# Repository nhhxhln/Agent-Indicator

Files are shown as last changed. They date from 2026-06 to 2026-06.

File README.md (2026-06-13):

# Agent Indicator

中文 | [English](README.en.md)

> 一个为 LLM Agent 打造的状态指示桌搭:让 Claude Code 的思考、回复、工具调用、
> 用量与 context 占用,变成桌面上一眼可读的光与屏。

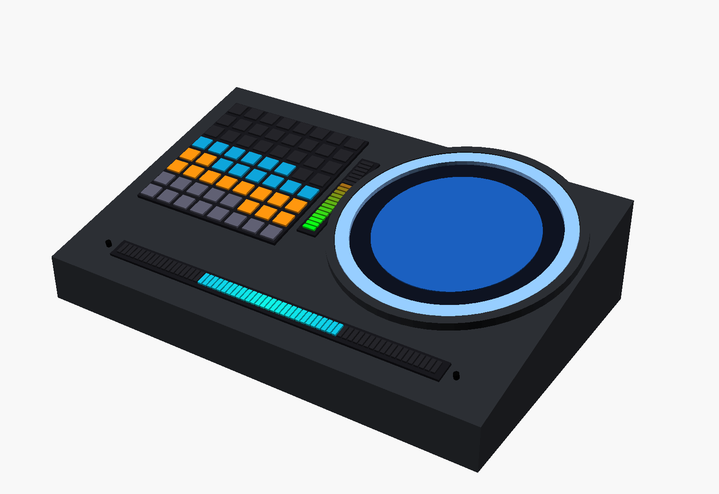
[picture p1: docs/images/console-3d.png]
Console 主力款


## ✨ 它能做什么

| 信息 | 载体 | 效果 |
|---|---|---|
| Agent 状态 | RGB Circle ×24 | 思考=紫色彗星旋转 · 回复=绿色流光 · 工具=双彗星对转 · 等待=蓝色呼吸 |
| Context 占用 | RGB Matrix 8×8(可 4 块拼 16×16) | 按 system/tools/mcp/memory/messages 分类的热力图 |
| 用量额度 | RGB Bar 20LED | 会话/5h 限额双段渐变条 |
| 输入输出 | 480×480 圆形视觉 LCD + 触摸 | 文本流 + 六页触摸 UI |
| 拾音电平 | RGB Bar(最长 160LED@329mm) | 中心展开 VU,MIC 本地闭环 |
| 提示音 | ES8311 + 3W PA | 完成/注意/错误三种音色 |
| 灯效模式 | 全部灯带 | OpenRGB 风格:常亮(调色)/呼吸/跑马灯/彩虹/关闭 |
| 环境传感 | SHT4x / BMP280 / PCF8563 | 温湿度 / 气压 / RTC 时钟,Devices 页实时显示 |
| 界面主题 | LCD | Light / Dark 双主题,Devices 页一键切换,NVS 持久化 |

**三链路接入**:Wi-Fi(WebSocket + mDNS 自发现)/ CAN(SocketCAN)/ USB 自定义端点,
同时在线自动择路。**电源**:USB-PD 15V / XT30 12-24V / 3×18650 平衡充,NVDC 无缝切换。

## 🖼️ 外观方案(6 款,共用同一主板)

| A「Halo」圆形单体 | D「Tiles」磁吸模块 | F「Orb」球形桌宠 |
|:---:|:---:|:---:|
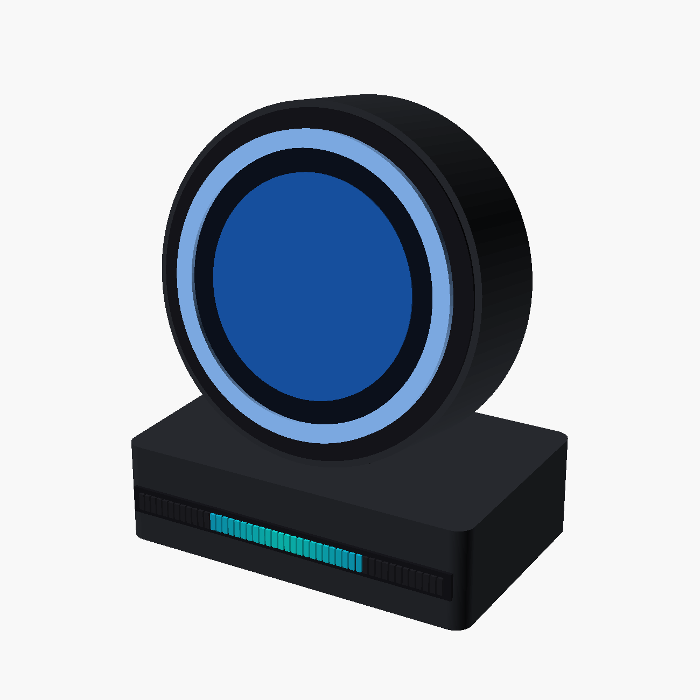
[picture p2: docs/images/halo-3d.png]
Halo
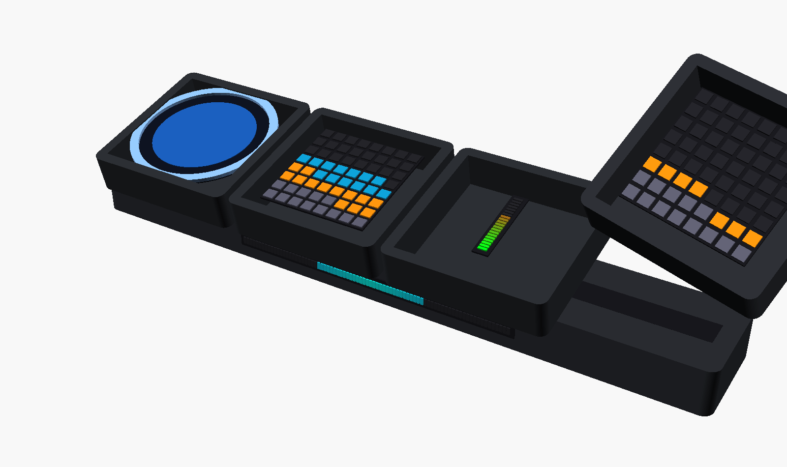
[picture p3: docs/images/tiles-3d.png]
Tiles
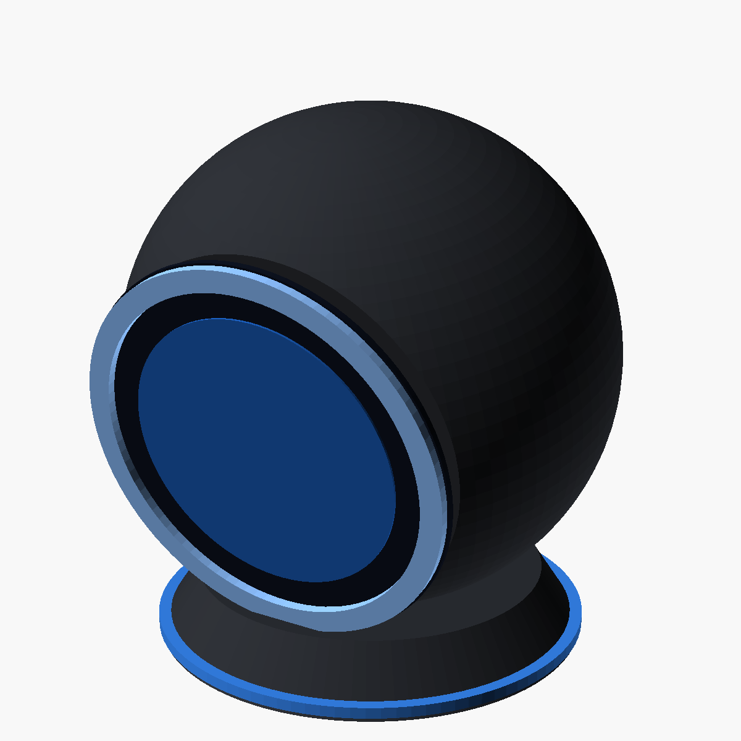
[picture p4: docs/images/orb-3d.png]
Orb
|  |  |  |

| B「Console」(推荐主力款) | E「Soundbar」(显示器下横条) |
|:---:|:---:|
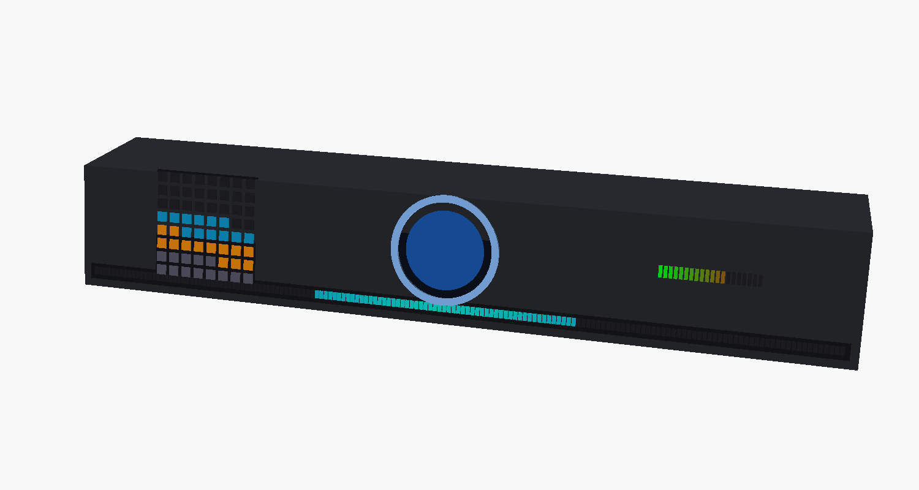
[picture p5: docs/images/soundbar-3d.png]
Soundbar
| Console |  |

> 另有 C「Totem」竖塔款,详见 [外观设计文档](docs/03-industrial-design.md)。

## 📱 屏幕 UI(六页 + Light/Dark 主题,PC 模拟器渲染 = 固件像素一致)

| Home 状态+IO 流 | Lighting 灯效 | Wi-Fi 连接 |
|:---:|:---:|:---:|
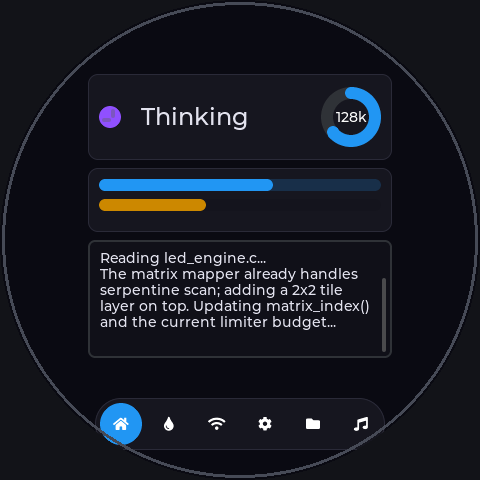
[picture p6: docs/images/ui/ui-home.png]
Home
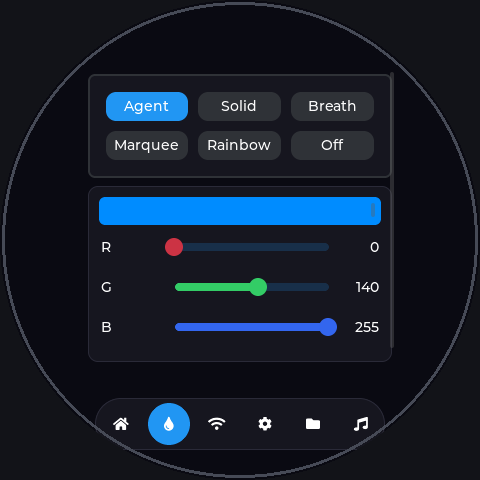
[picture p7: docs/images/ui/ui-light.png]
Lighting
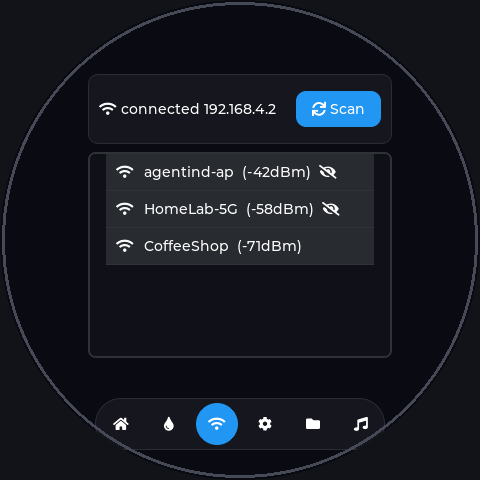
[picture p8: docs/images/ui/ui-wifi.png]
Wi-Fi
|  |  |  |

| Devices 检测+传感器 | Files 浏览 | Music 播放 |
|:---:|:---:|:---:|
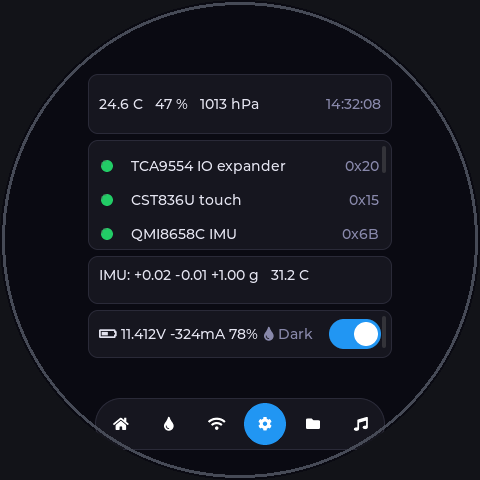
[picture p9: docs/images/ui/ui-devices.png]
Devices
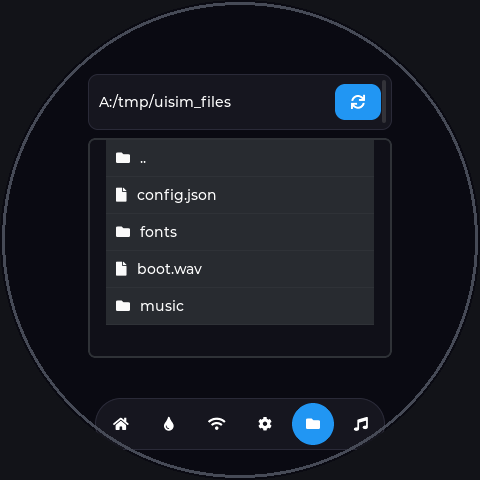
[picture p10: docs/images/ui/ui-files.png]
Files
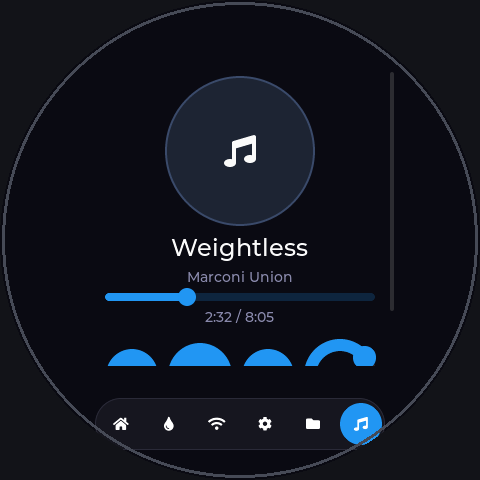
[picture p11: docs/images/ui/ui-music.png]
Music
|  |  |  |

| Dark 主题(默认) | Light 主题 |
|:---:|:---:|
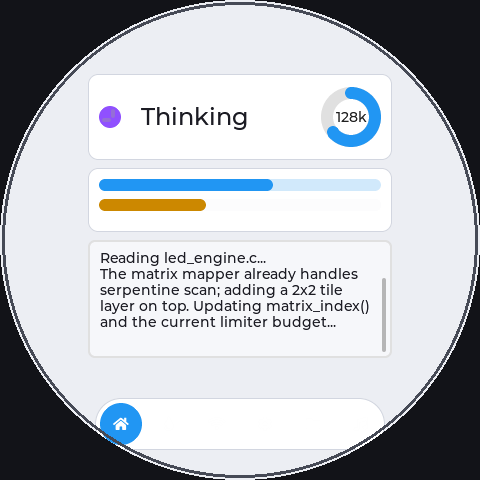
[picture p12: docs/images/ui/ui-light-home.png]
Home light
| Home dark |  |

## 🚀 快速开始

```bash
# 1. 固件(ESP-IDF v5.2)
cd firmware && idf.py set-target esp32s3 && idf.py menuconfig   # 填 Wi-Fi SSID
idf.py build flash monitor

# 2. 上位机(PC 先建好 AP)
cd host && pip install -e . && agentind run        # Claude Code 状态自动转发
agentind run -s demo -v                             # 或先跑演示动画联调

# 3. UI 模拟器(可选,PC 上改 UI 不烧板)
cd tools/ui_sim && cmake -B build && cmake --build build -j && ./build/ui_sim shots/
```

## 📚 文档导航

| 文档 | 内容 |
|---|---|
| [01 系统设计](docs/01-system-design.md) | 架构、器件选型、模块详设、三链路协议 |
| [02 电源设计](docs/02-power-design.md) | PD/XT30/3S 拓扑、充电均衡保护、功耗预算 |
| [03 外观设计](docs/03-industrial-design.md) | 6 方案 + 3D 渲染 + 对比选型 |
| [04 原理图划分](docs/04-schematic-partition.md) | 8 页划分、完整 pinmap、LCD 40P 定义、布局 |
| [05 屏幕 UI](docs/05-ui-design.md) | 六页 UI 设计 + 模拟器用法 |
| [host/README](host/README.md) | 上位机安装、Claude Code hooks 接入 |
| [firmware/README](firmware/README.md) | 编译烧录、测试控制台命令表、任务栈约定 |

## 📂 仓库结构

```
docs/            设计文档(中文)· docs/en/ 英文版 · docs/images/ 渲染图与 UI 截图
hardware/3d/     OpenSCAD 模型源文件 + 可打印 STL(6 款外观)
host/            Python 桥 agentind:状态源 → 协议 → ws/can/usb
firmware/        ESP-IDF v5.2:三链路 comm / LED 引擎+灯效 / LVGL9 六页 UI /
                 音频五项 case / CAN case / IMU 可视化 / 测试控制台(UART)
tools/ui_sim/    LVGL PC 无头模拟器(与固件共用 UI 源码,出文档截图)
```

## 🗺️ 路线图

- [x] 设计文档 / 电源方案 / 协议 / 固件框架 / 上位机
- [x] LVGL 六页 UI + 灯效引擎 + PC 模拟器
- [ ] 原理图绘制(KiCad)与主板打样
- [ ] ST7701 屏厂初始化序列核对、USB vendor 描述符
- [ ] Console(方案 B)结构件打印与整机联调
- [ ] Tiles 模块化(pogo 枚举协议)二期

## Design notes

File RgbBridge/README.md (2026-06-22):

# RgbBridge — SPI → ST7701S 480×480 RGB 桥

用**第二颗 ESP32-S3** 专门驱动 ST7701S(480×480 RGB565)并口屏。主板(Agent Indicator)
只需出 **4 根 SPI** 把帧推给桥片,RGB 那 ~24 根线全留在桥片上 → **主板省下约 20 个 GPIO**。

桥片**不接主机也能自测点亮**(开机循环纯色/彩条/渐变/棋盘/边框),收到主机帧后自动让位。

## 为什么面板侧是 RGB565
ESP32-S3 的 RGB 并口**最多 16 根数据线 = RGB565**,做不了 24 位 RGB888 并口。
所以面板输出固定 RGB565;**主机推 565 或 888 都收**,888 在桥片上转 565(协议里 `fmt` 标记)。

## 引脚(`main/board.h`,按实际接线改)
| 用途 | GPIO |
|---|---|
| RGB565 数据 B0-4 / G0-5 / R0-4 | 4,5,6,7,8 / 9,10,11,12,13,14 / 15,16,17,18,21 |
| PCLK / DE / VSYNC / HSYNC | 39 / 40 / 41 / 42 |
| ST7701 初始化 3 线 SPI:CS / SCL / SDA | 45 / 47 / 48 |
| RST / 背光 BL | 46 / 44 |
| 主机 SPI 从机:CS / CLK / MOSI / MISO | 1 / 2 / 38 / 43 |

> 避开了 flash(26-32)/PSRAM(33-37)/USB(19-20)/BOOT(0)。strap 脚 45/46 仅作输出,安全。

## 编译烧录
```bash
. /home/zhe/Code/esp-idf/export.sh
cd RgbBridge
idf.py set-target esp32s3      # 首次(会拉取 esp_lcd_st7701 + panel_io_additions)
idf.py build flash monitor
```
开机即应看到屏幕循环切换测试图案。**不亮/偏色先看下面两个调点。**

## 初始化序列(两版可切)
`board.h` 的 `USE_VENDOR_INIT`:
- **1(默认)**= 面板厂商专属序列(转自 `LCD_INIT_CMD.txt`,Gamma/VCOM/电压针对本屏,在 `rgb_panel.c` 的 `s_vendor_init[]`);
- **0** = esp_lcd_st7701 组件内置通用默认序列。
偏色/不亮就两版都试。

## ⚠ 上板还需按手册调一处:RGB 时序
`LCD_INIT_CMD.txt` 只含初始化命令,**不含 RGB 时序**。`board.h` 的 `RGB_PCLK_HZ` 与前后肩/同步宽度
仍是常见默认值,按你面板手册的 RGB timing 填准(错了会花屏/滚动/不同步)。先用默认 16MHz 试。
注:厂商序列里 `COLMOD=0x66`(RGB666 18bit),16 根数据线接面板高位即可(RGB565→666 丢各色 1 LSB)。

## 主机侧线协议(主板要按这个推帧)
SPI 主,模式 0;**每个 SPI 事务 = 一行包**:

| 字节 | 含义 |
|---|---|
| [0] | `0xA9` 魔数(帧同步) |
| [1] | 格式:`0`=RGB565 小端,`1`=RGB888 |
| [2..3] | 行号 y(小端 u16) |
| [4..] | 该行 480 个像素(565:960B;888:1440B) |

主机连续推 y=0..479,桥片收到 `y==479` 即整帧刷新上屏;收到首个合法包后自测停止。
（这是 v1:简单逐行 + 帧同步;后续要更高帧率可改双缓冲/DMA 链 + 握手 GPIO。）

## 状态
- ✅ 自测点亮:已实现,编译通过(待上板验证时序/初始化序列)。
- ✅ SPI 从机接收 565/888:已实现,编译通过(主机侧推帧代码待在主板 firmware 配套实现/联调)。

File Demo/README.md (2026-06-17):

# Agent Indicator — Demo 测试工程

基于主固件裁剪,按测试用引脚配置:**LCD 换 GC9A01(SPI, 240×240 圆屏)**,
音频默认 **WM8960**,所有总线(SDMMC/I2C/I2S/TWAI/USB)同时启用。
目标板 **ESP32-S3-DevKitC-1(N16R8)** + 转接板。

## 引脚配置

| 外设 | 引脚 |
|---|---|
| LCD GC9A01(SPI) | CS=10, MOSI=11, SCLK=12, MISO=13, DC=14;RST 软复位,BL 接 VCC 常亮 |
| 音频 WM8960(I2S) | MCLK=1, BCLK=2, LRCK/WS=42, SDIN(ESP→codec)=41, DOUT(codec→ESP)=40 |
| I2C(触摸/codec/IMU/传感器) | SDA=39, SCL=38 |
| WS2812 ×2 | matrix=48, aux=45 |
| SDMMC(1 线) | CLK=4, CMD=5, DAT0=6 |
| TWAI(CAN) | TX=47, RX=21 |
| USB(USB-Serial-JTAG:日志/下载/REPL) | D-=19, D+=20 |
| 切页按钮 | BOOT(GPIO0) |

> SPI 屏省线后 21 根 GPIO 即可,全部互不冲突。SDMMC 未插卡只报错不 panic。
> WM8960 必须有 MCLK(已接 GPIO1);codec 默认探测 WM8960(0x1A),无则回落 ES8311(0x18)。

## 编译烧录

```bash
. /home/zhe/Code/esp-idf/export.sh
cd Demo
idf.py set-target esp32s3      # 首次
idf.py build flash monitor
```

## 测试方法

- **屏幕 UI**:开机显示六页圆形 UI。GC9A01 无触摸时 **按 BOOT 键轮播切页**
  (Home→Lighting→Wi-Fi→Devices→Files→Music);接了 CST816 触摸版则可触摸。
- **设备检测**:Devices 页(齿轮)看各外设绿/红点 + 环境读数(温湿度/气压/RTC)。
- **灯效**:Lighting 页切 Solid/Breath/Marquee/Rainbow;或控制台 `light rainbow`。
- **音频**:`tone 0`、`audio_loop on`、`audio_rec 5`+`audio_play`、
  `audio_rec_sd test 5`(需插卡)、`audio_player /sdcard/x.wav`、`audio_vol 60`。
- **CAN**:`can_tx 10 100` 发帧(PC `candump can0`);`can_rx on` 监听。
- **I2C 调试**:`i2cdetect` 扫描总线(确认 WM8960=0x1A 等是否在位);
  `i2cget <addr> <reg> [len]`、`i2cset <addr> <reg> <b0..>`(均 hex)。
- **SD**:`sd mount` / `ls /sdcard`。
- **IMU**:`imu` 单次,`imu_vis on` 可视化。
- **Wi-Fi**:PC 建 AP(SSID 见 menuconfig),设备自动连;host 跑 `agentind run`。
- **控制台**:USB 口 `idf.py monitor`,输入 `help` 看全部命令。

## 与主固件的差异

| | 主固件(firmware/) | Demo |
|---|---|---|
| LCD | ST7701 480×480 RGB(20 线) | **GC9A01 240×240 SPI(5 线)** |
| 音频默认 | ES8311 | **WM8960**(运行时仍兼容 ES8311) |
| SD/CAN | DevKitC-1 引脚不足默认禁用 | **默认启用**(SPI 屏腾出引脚) |
| 切页 | 触摸 | 触摸或 **BOOT 键** |

UI 源码与主固件共用(`main/ui/screens/`),仅安全区/字号按 240 圆屏缩放。

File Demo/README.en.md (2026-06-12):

# Agent Indicator Firmware (ESP-IDF v5.2)

[中文](README.md) | English

## Build & Flash

```bash
. /home/zhe/Code/esp-idf/export.sh
idf.py set-target esp32s3
idf.py menuconfig        # "Agent Indicator" menu: Wi-Fi SSID/password, matrix tiles, VLED budget
idf.py build flash monitor
```

## Layout

```
main/
  board.h            pinmap (matches docs/en/04 §2 — board changes happen here only)
  app_main.c         boot order
  app_state.{h,c}    global state model: comm writes, ui/audio consume; text ring buffer
  proto/             protocol frames (mirrors host/agentind/protocol.py)
  bus/i2c_bus.cpp    shared I2C bus + TCA9554 expander (no-op fallback when absent)
  storage/           SPIFFS (/spiffs) + microSD 1-bit (/sdcard)
  console/           esp_console REPL @ USB Serial/JTAG, case registration hub
  comm/              comm_wifi (WS server + mDNS) / comm_twai (0x500/0x580 segments)
                     / comm_usb (TinyUSB vendor skeleton; exclusive with the REPL)
  ui/                led_engine (60fps, current limiter, 1 or 4 matrix tiles)
                     display (ST7701 3-wire-init + LVGL9 + CST820 + TinyTTF)
                     i18n (zh/en string tables, NVS-persisted)
  audio/audio.cpp    ES8311 full-duplex 16k/16bit; one capture task feeds VU/rec/loopback
  drivers/qmi8658.cpp QMI8658C minimal driver (±8g/±512dps)
  cases/             CAN / IMU test cases (audio cases live in audio.cpp)
  power/power.c      telemetry task (INA226/MP2760/cell ADC pending bring-up)
```

## Test Console (USB Serial/JTAG, available in `idf.py monitor`)

| Command | Function |
|---|---|
| `can_tx [count] [period_ms]` | send incrementing frames (ID 0x123); pair with `candump can0` |
| `can_rx [on\|off]` | bus monitor (turn off while testing protocol frames — competes with comm_twai) |
| `can_status` | TWAI state / error counters |
| `audio_rec [sec]` | record to PSRAM (≤30s) |
| `audio_play` | replay the PSRAM recording |
| `audio_rec_sd <name> [sec]` | record to `/sdcard/<name>.wav` |
| `audio_player <path>` | play a WAV (`/sdcard` or `/spiffs`, PCM16) |
| `audio_loop [on\|off]` | MIC→SPK passthrough |
| `audio_vol <0-100>` / `tone <0-3>` | volume / chimes |
| `imu` / `imu_vis [on\|off]` | one-shot read / live view (LCD horizon + 6-axis bars, logs without LCD) |
| `sd [mount\|umount]` / `ls [path]` | SD management / list dir |
| `lang [zh\|en]` | UI language (persisted in NVS) |

## Task Stacks (C++ module notes)

| Task | Stack | Notes |
|---|---|---|
| LVGL (esp_lvgl_port) | 10240 | TinyTTF rasterization runs here |
| console REPL | 8192 | commands run on this task (audio_play blocks until done) |
| audio player | 8192 | vfs + WAV parsing |
| audio capture | 6144 | file-write path |
| imu_vis / disp_text | 6144 | LVGL calls + float printf |
| can_tx/can_rx | 4096 | driver + log only |

New code is C++17 with `extern "C"` across the C boundary; task entry points must not
throw (exceptions disabled); no large buffers on stacks (>512B goes static or heap).

## Bridge bring-up (works without any peripherals)

```bash
# PC side (AP already up)
cd ../host && pip install -e . && agentind run -s demo -v
```

All hardware dependencies (LCD/audio/IMU/expander) are runtime-probed; a bare
ESP32-S3 module is enough to exercise Wi-Fi + protocol + state machine, with the
text stream degraded to monitor logs.

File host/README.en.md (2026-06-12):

# agentind — Host Bridge

[中文](README.md) | English

Reads LLM (Claude Code) state, encodes it per the
[protocol](../docs/en/01-system-design.md#5-protocol-host--device) and pushes it to the
Agent Indicator over Wi-Fi WebSocket / SocketCAN / USB vendor EP.

## Install

```bash
cd host
pip install -e .            # base (ws)
pip install -e ".[all]"     # + can/usb
```

## Run

```bash
agentind run                          # claude-code source + mDNS discovery (Wi-Fi)
agentind run -s demo -v               # demo animations for hardware bring-up
agentind run -t can --channel can0    # SocketCAN (ip link set can0 up type can bitrate 500000)
agentind run -t usb                   # USB custom endpoints (303a:82a9)
```

## Claude Code integration

By default it tails `~/.claude/projects/**/*.jsonl` to infer state. For lower latency
add hooks in `~/.claude/settings.json` that POST events to the built-in listener
(127.0.0.1:8765) — see the Chinese README for the JSON snippet (identical config).

## Layout

```
agentind/
  protocol.py        frame encode/decode, messages (mirrors firmware main/proto)
  transports/        ws (mDNS discovery) / can (segmentation) / usb (bulk EP)
  sources/           claude_code (JSONL tail + hooks listener) / demo
  cli.py             agentind run
```

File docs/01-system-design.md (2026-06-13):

# Agent Indicator — 系统设计总览

> LLM 状态指示桌搭 · Rev 0.2 · 2026-06
> English version: [en/01-system-design.md](en/01-system-design.md)
> 配套文档:[02-power-design.md](02-power-design.md) 电源 · [03-industrial-design.md](03-industrial-design.md) 外观 · [04-schematic-partition.md](04-schematic-partition.md) 原理图

## 1. 功能定义

| 功能 | 载体 | 说明 |
|---|---|---|
| LLM Usage 展示 | RGB Bar(20 LED 竖条/分段) | 会话用量、5h/周限额等多槽位百分比条 |
| LLM Status 展示 | RGB Circle(24 LED) | idle / thinking / responding / tool-use / error 等状态动画 |
| LLM Context 展示 | RGB Matrix(8×8,固件兼容 4 块拼 16×16) | context window 占用热力图 / 分类色块 |
| LLM 输入输出 | LCD(ST7701 480×480 + CST836U 触摸) | 滚动显示 prompt/response 摘要,触摸翻页 |
| 拾音电平 | RGB Bar(横向长条) | 本地 MIC VU 表 / 提示音可视化 |
| 提示音 / 拾音 | I2S Codec + PA + MEMS MIC | 任务完成提示音、语音输入电平 |

扩展接口:SDMMC(资源/录音)、CAN/TWAI(总线接入)、USB Device(自定义 EP + CDC)、I2C 外扩(触摸 + 传感器)。

## 2. 系统框图

```
                        ┌────────────────────────────────────────────┐
   Linux PC (Host)      │              Agent Indicator               │
  ┌──────────────┐      │  ┌──────────────────────────────────────┐  │
  │ agentind     │ WiFi │  │           ESP32-S3-WROOM-1-N16R8     │  │
  │ (Python 转发)│◄────►│  │                                      │  │
  │  - 状态源    │ CAN  │  │ RGB-LCD16bit ──► ST7701 480×480 LCD  │  │
  │  - 协议编码  │◄────►│  │ I2C ──► CST836U / QMI8658C / TCA9554  │  │
  │  - 多路传输  │ USB  │  │            / INA226 / MP2760         │  │
  └──────────────┘◄────►│  │ RMT×2 ──► WS2812B Matrix / Ring+Bars │  │
                        │  │ I2S ──► ES8311 ──► NS4150B ──► SPK   │  │
                        │  │              ▲MIC                    │  │
                        │  │ SDMMC 1-bit ──► microSD              │  │
                        │  │ TWAI ──► TJA1051T/3 ──► CAN(XT30 旁) │  │
                        │  │ USB-OTG ──► Type-C(数据,与 PD 口分开)│  │
                        │  └──────────────────────────────────────┘  │
                        │  电源:PD(15V)/XT30(12-24V)/3S 18650      │
                        └────────────────────────────────────────────┘
```

## 3. 器件选型

### 3.1 主控

| 项 | 选型 | 理由 |
|---|---|---|
| MCU 模组 | **ESP32-S3-WROOM-1-N16R8** | 16MB Flash + 8MB Octal PSRAM。RGB LCD 480×480×RGB565 帧缓冲 ≈460KB 必须放 PSRAM;LCD_CAM 外设直驱 RGB 屏;原生 USB-OTG;TWAI;RMT 驱 WS2812;Wi-Fi |

注意:N16R8 的 Octal PSRAM 占用 GPIO35/36/37,引脚预算见 04 文档 pinmap。

### 3.2 外围芯片

| 功能 | 选型 | 备选 | 说明 |
|---|---|---|---|
| CAN 收发器 | **TJA1051T/3** | SIT1051T(国产) | /3 版本 VIO 3.3V,无需电平转换;5V 供电自 5V0 |
| Audio Codec | **ES8311**(默认)/ **WM8960**(同时支持) | ES8388 | 固件运行时按 I2C 地址自动探测:ES8311@0x18(单声道,BCLK 作 MCLK 省 GPIO)/ WM8960@0x1A(立体声,**需 MCLK**,接 `BOARD_I2S_MCLK`)。两者引脚一致,二选一焊装 |
| Audio PA | **NS4150B** | MAX98357(纯 I2S 方案) | 3W Class-D,Espressif 官方板同款搭配;EN 脚接 IO 扩展器 |
| MIC | **MSM261(模拟 MEMS)→ ES8311 MIC_IN** | INMP441(I2S 数字,需多占线) | 走 codec 模拟输入,省 I2S 线;拾音条 VU 由固件 RMS 计算 |
| IMU | **QMI8658C** | LSM6DS3TR-C | 6 轴,I2C,带敲击/抬手中断,资料多价格低;用于敲击交互、姿态感知翻转显示 |
| 触摸 | **CST836U**(随屏) | — | I2C 0x15,与 CST816 同协议族,可用 `esp_lcd_touch_cst816s` 驱动 |
| IO 扩展 | **TCA9554** | PCA9554 | LCD_RST / TP_RST / PA_EN / BL_EN / LED_PWR_EN 等慢速控制,缓解 GPIO 紧张 |
| 电流监控 | **INA226** | INA219 | 挂 VSYS 高侧,电量/功耗遥测上报 |
| LED 电平转换 | **SN74AHCT125** | 74HCT245 | 3.3V→5V 数据,WS2812B 在 5V 供电下 VIH=3.5V,必须转换 |

电源链路器件(CH224K / MP2760 / S-8254A / HY2213 / TPS56637 / MP2315S / TPS2121 / SGM2212)见 [02-power-design.md](02-power-design.md)。

### 3.3 显示与灯

| 项 | 参数 |
|---|---|
| LCD | ST7701S,480×480,16-bit RGB565 并口 + 3-wire SPI 初始化(SPI 线借用 RGB 数据线,Espressif 参考设计同款做法);外形 73.03×76.48mm,AA 70.13×70.13mm |
| RGB Matrix | WS2812B 8×8,64×64mm,板对板/排线级联,固件支持 1/4 块(16×16)拼接,S 形扫描可配置 |
| RGB Circle | WS2812B ×24,ID 75 / OD 85mm |
| RGB Bar | 按外形方案选长度:Usage 竖条 20LED@41.5mm;拾音条 48LED@99mm 或 64LED@132mm(见 03 文档各方案) |

## 4. 模块详设

### 4.1 LED 子系统

- **驱动**:RMT ×2 通道(`led_strip` 组件,DMA 模式)。
  - CH0 `LED_MATRIX`:matrix 链(1~4 块菊花链,64~256 颗)。
  - CH1 `LED_AUX`:circle(24)→ usage bar(20)→ 拾音条(48/64),一条链逻辑分段寻址。
- **刷新**:60fps 动画引擎,链长 172 颗 @800kHz ≈5.2ms,余量充足。
- **限流**:固件全局电流限制器——按帧累加理论电流(每通道 16mA 折算),超 VLED 预算(4.5A)整帧等比降亮。16×16 拼接时尤其必要。
- **供电**:VLED 5V/5A,LED_PWR_EN(TCA9554)控制 PMOS 开关,休眠彻底断电。

### 4.2 LCD 子系统

- `esp_lcd` RGB panel + `esp_lcd_st7701`(managed component),双 bounce buffer 抗 PSRAM 带宽抖动;PCLK 20MHz 起步(后期可上调)。
- LVGL 9(`esp_lvgl_port`):I/O 文本流页面、状态页、设置页;CST836U 触摸滑动切页。
- 背光:BL_EN(TCA9554)开关 + 屏内容自适应调光;若需硬件 PWM 调光,牺牲 TWAI_TX 引脚换(pinmap 中注明)。

### 4.3 音频子系统

- ES8311:I2S 从机,BCLK 作内部 MCLK(`MCLK from SCLK` 模式),16kHz/16bit 拾音,44.1kHz 提示音播放。
- 提示音:SD 卡或 flash 内嵌 WAV;`esp_codec_dev` 统一读写。
- 拾音条:ADC 流 20ms 窗口 RMS → dB 映射 → 拾音 bar 渐变,本地闭环不经上位机。

### 4.4 通讯子系统(三链路并存,统一协议层)

| 链路 | 实现 | 场景 |
|---|---|---|
| Wi-Fi | 设备起 WebSocket server(`esp_http_server`)+ mDNS `_agentind._tcp`;PC 做 AP,host 经 zeroconf 发现后连接 | 主链路,桌面摆放无线 |
| CAN | TWAI 500kbps,11-bit ID,>8B 消息用轻量分段(见 §5.3);PC 侧 USB-CAN + SocketCAN | 工控/多设备总线 |
| USB | TinyUSB 复合设备:Vendor class bulk EP(协议帧)+ CDC(日志/调试) | 直连零配置、固件调试 |

三条链路同时监听,最近收到有效帧的链路为"活动链路";遥测向活动链路回报。

### 4.5 电源管理

- MP2760(I2C)+ INA226 + 3S 电压采样 → 电量估算、充电状态;低电量时 circle 边缘呼吸红色提醒。
- 无活动 5min:LCD 降亮、LED 切低亮时钟/呼吸待机;30min:断 VLED、LCD 休眠,触摸/IMU 敲击唤醒。

## 5. 通讯协议(host ↔ device)

### 5.1 帧格式(WS / USB / CDC 通用)

```
┌──────┬─────┬──────┬──────┬─────────┬─────────┬───────┐
│ 0xA9 │ VER │ TYPE │ FLAGS│ LEN(LE) │ PAYLOAD │ CRC16 │
│  1B  │ 1B  │  1B  │  1B  │   2B    │  ≤512B  │  2B   │
└──────┴─────┴──────┴──────┴─────────┴─────────┴───────┘
```
- VER=0x01;CRC16-CCITT(覆盖 VER..PAYLOAD);WS binary message 一帧一消息。

### 5.2 消息类型

| TYPE | 方向 | 名称 | Payload |
|---|---|---|---|
| 0x01 | H→D | STATE | `u8 state, u8 detail`。state: 0 IDLE / 1 CONNECTING / 2 THINKING / 3 RESPONDING / 4 TOOL_USE / 5 WAITING_USER / 6 ERROR / 7 RATE_LIMITED / 8 OFFLINE |
| 0x02 | H→D | USAGE | `u8 n, n×{u8 slot, u8 percent}`。slot: 0 会话 / 1 5h 限额 / 2 周限额 / 3 成本 |
| 0x03 | H→D | CONTEXT | `u32 used, u32 total, u8 n, n×{u8 category, u32 tokens}`。category: system/tools/mcp/memory/messages/free |
| 0x04 | H→D | TEXT | `u8 stream(0 in/1 out), u8 op(0 append/1 replace/2 clear), utf8[]` |
| 0x05 | H→D | TONE | `u8 tone_id`(0 done / 1 attention / 2 error / 3 boot) |
| 0x06 | H→D | CONFIG | `u8 key, u32 value`。key: 0 亮度 / 1 matrix 块数(1\|4)/ 2 方向 / 3 UI 语言(0 en, 1 zh)/ 4 灯效([15:8]=模式 0-5,[7:0]=速度)/ 5 灯效颜色 0xRRGGBB(先于 key=4 发) |
| 0x80 | D→H | TELEMETRY | `u16 vbat_mV ×3cell, i16 ibat_mA, u8 soc, u8 chg_state, u8 src(0 bat/1 pd/2 xt30)` |
| 0x81 | D→H | INPUT | `u8 kind(0 touch/1 imu_tap/2 imu_shake), u8 arg` |
| 0x82 | D→H | MIC_LEVEL | `u8 db`(可选订阅) |

### 5.3 CAN 映射

11-bit ID = `0x500 | TYPE 低 5 位`;Payload >7B 时分段:`byte0 = (seq<<4)|total`,首段 byte1 为 TYPE 原值。TELEMETRY 单帧直发 `0x580`。

## 6. 软件交付物

```
host/      Python 包 agentind:状态源(Claude Code hooks/JSONL)→ 协议编码 → ws/can/usb 传输
firmware/  ESP-IDF v5.2 工程:comm(三链路)/ proto / ui(matrix·ring·bar·lcd)/ audio / power
           + storage(SPIFFS/SD)/ console(测试 REPL)/ cases(CAN·Audio·IMU 测试)
```

详见各目录 README。

## 7. 固件平台能力(v0.2 新增)

| 能力 | 实现 | 说明 |
|---|---|---|
| 文件系统 | SPIFFS(6MB `storage` 分区 → `/spiffs`)+ microSD(1-bit SDMMC → `/sdcard`,支持热插拔挂载) | LVGL 经 `LV_USE_FS_POSIX` 以盘符 `A:` 直接访问两者 |
| 矢量字体 | LVGL TinyTTF(基于 stb_truetype,**非 FreeType**) | 开机检测 `/spiffs/fonts/ui.ttf` 自动加载;支持 .ttf 与 TrueType 轮廓的 .otf,**不支持 CFF/PostScript 轮廓的 .otf**,无 hinting/kerning。需要完整 OTF 时可换 `lv_freetype` + FreeType(约 +600KB) |
| UI 多语言 | `ui/i18n.c` 中英字符串表,NVS 持久化 | 控制台 `lang zh\|en` 或协议 CONFIG key=3 切换;中文渲染需 CJK TTF(内置 Montserrat 无中文字形) |
| LVGL | LVGL9 + esp_lvgl_port,双 FB direct mode + bounce buffer 抗撕裂 | LVGL 任务栈 10KB(TinyTTF 栅格化在该任务执行) |
| 测试控制台 | esp_console REPL @ USB Serial/JTAG | 与 TinyUSB vendor EP 互斥(同一 USB PHY),量产固件二选一 |
| 测试 case | CAN tx/rx、Audio rec/replay/player_from_sd/rec_to_sd/loopback、IMU 可视化 | C++ 实现(`cases/`),命令清单见 firmware/README;无屏/无外设时自动降级日志模式 |
| C++ 支持 | 新模块以 C++17 编写,经 `extern "C"` 与 C 框架互操作 | 任务栈显式标定:LVGL 10K / REPL 8K / player 8K / capture 6K / imu_vis 6K / can 4K |

### 7.1 音频数据流设计

单一 capture 任务独占 I2S RX:常态计算 VU(拾音条),录音(RAM/SD)与
loopback 复用同一数据流按模式分发;TX 由互斥锁串行化(tone/player/loopback
不并发),避免多任务争抢 I2S 句柄。

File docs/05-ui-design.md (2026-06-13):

# Agent Indicator — 屏幕 UI 设计

> Rev 0.2 · English version: [en/05-ui-design.md](en/05-ui-design.md)
> 截图由 `tools/ui_sim`(LVGL PC 无头渲染)生成,与固件渲染像素一致。
> UI 代码位于 `firmware/main/ui/screens/`,固件与模拟器共用同一份源码。

**⚠ 圆形屏适配**:LCD 为 **480×480 圆形**显示区(AA 内的圆,四角不可见),
故 UI **不用 lv_tabview**(其全宽底栏与贴边卡片的四角会被圆裁掉)。改为:

- 内容限制在**居中安全区**(320×300,落在 R240 圆内),顶部留 66px 圆窄区;
- 导航为**底部居中 pill**(宽 290,落在底部弦内),6 图标切页;
- 截图均叠加圆形遮罩呈现真实可视区,圆外为面板外壳。

所有页面的数据更新接口(`ui_*_set`)内部带锁,可从任意任务调用;支持 Light/Dark 主题(§7)。

## 1. Home — 状态与 I/O 流

Home

- 顶栏:状态色点 + 状态名(跟随 i18n 语言)+ context 占用圆环(`128k`);
- 双用量条:会话(蓝)/ 5h 限额(橙),数据来自 USAGE 消息;
- 下方为 LLM 输入输出文本流(TEXT 消息,4KB 滚动窗口)。

## 2. Lighting — 灯效控制(参考 OpenRGB 预设)

Lighting

- 模式:**Agent**(默认状态驱动)/ **Solid** 常亮 / **Breath** 呼吸 /
  **Marquee** 跑马灯 / **Rainbow** 彩虹流动 / **Off**;
- RGB 三滑条 + 实时预览色块;Speed(1-100)与全局亮度;
- 等效控制途径:控制台 `light <mode> [RRGGBB] [speed]`、协议 CONFIG key=4/5;
- 覆盖灯效将 matrix+circle+bars 视为一条逻辑灯带统一渲染,限流器仍生效。

## 3. Wi-Fi — 连接管理

Wi-Fi

- 状态行(已连接 IP / disconnected)+ Scan 按钮(esp_wifi 异步扫描);
- 网络列表(RSSI + 加密标记),点击弹出全屏密码键盘,确认后
  `esp_wifi_set_config` 存 NVS 并重连。

## 4. Devices — 传感器与设备检测(= 设置页)

Devices

自上而下四个区:

1. **环境读数卡**:温度 ℃ / 湿度 % / 气压 hPa(SHT4x + BMP280)+ 右侧 RTC 时钟,500ms 刷新;
2. **设备检测表**(可滚动,11 项):绿点=在位 / 红点=缺失,右列为 I2C 地址或状态。开机 `sensors_init` + `i2c_probe` 探测一次:

   | 设备 | 地址 | 说明 |
   |---|---|---|
   | TCA9554 IO expander | 0x20 | 慢速控制扩展 |
   | CST836U touch | 0x15 | 电容触摸 |
   | QMI8658C IMU | 0x6B | 6 轴 |
   | Audio codec | ES8311/WM8960 | I2S + I2C,运行时探测 |
   | INA226 monitor | 0x40 | 功耗遥测 |
   | MP2760 charger | 0x5C | 充电管理 |
   | microSD | — | SDMMC 挂载状态 |
   | CAN bus | 500k | TWAI |
   | **SHT4x temp/humi** | **0x44** | **温湿度传感器** |
   | **BMP280 pressure** | **0x76** | **气压传感器(SDO=GND;0x77=SDO=VDD)** |
   | **PCF8563 RTC** | **0x51** | **I2C 实时时钟** |

3. **IMU 实时行**:6 轴加速度 + 温度,500ms 刷新;
4. **电源行 + 主题开关**:电压/电流/SoC,右侧 Light/Dark 开关(见 §7)。

新增三个 I2C 环境传感器驱动位于 `firmware/main/drivers/sensors.cpp`:SHT4x(0xFD 高精度测量)、
BMP280(读校准系数 + Bosch 定点补偿)、PCF8563(BCD 时间寄存器)。不在位时各 `*_present()`
返回 false,对应行显示红点。挂在共享 I2C 总线(Qwiic 座可直接接模块)。

## 5. Files — 文件浏览

Files

- 基于 LVGL FS(盘符 `A:` = POSIX VFS),可浏览 `/spiffs` 与 `/sdcard`;
- 目录点击进入,`..` 返回,路径栏循环滚动。

## 6. Music — 音乐播放

Music

- 曲目信息 + 进度条 + 播控(prev/play/next)+ 音量 arc(codec DAC 音量);
- 后端为 `audio_player`(SD 卡 WAV);播放列表 glue 标注 TODO。

## 7. 主题 Light / Dark

全 UI 支持亮/暗双主题,Devices 页右下角开关切换,**NVS 持久化**(重启保留)。
实现:`screens.c` 维护两套调色板 token(`t_bg/t_card/t_text/t_sub/t_area`),
切换时重新 `lv_theme_default_init`(内置控件)+ 按 token 重建 UI,
并通过 `on_rebuild` 回调让宿主重新填充数据。也可由协议或控制台驱动。

| Dark(默认) | Light |
|---|---|
| Home dark | Home light |
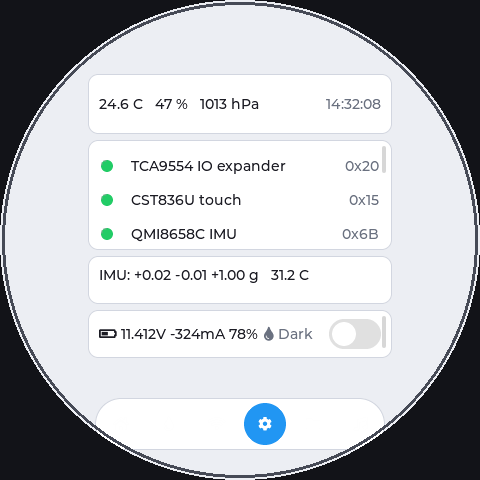
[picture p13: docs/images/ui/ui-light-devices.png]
Devices light
| Devices dark |  |

## 模拟器用法

```bash
cd tools/ui_sim
cmake -B build && cmake --build build -j   # 复用 firmware managed_components 里的 LVGL
./build/ui_sim shots/                      # 输出 ui-*.bmp(暗色)+ ui-light-*.bmp(亮色),共 12 张
```

注意:LVGL 必须配置为 CLIB malloc(固件 `CONFIG_LV_USE_CLIB_MALLOC`,
模拟器 `LV_USE_STDLIB_MALLOC=LV_STDLIB_CLIB`)——内置 64KB TLSF 池容不下
六页控件,OOM 后会在 `lv_obj_add_style` 内死循环。

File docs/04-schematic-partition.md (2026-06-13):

# Agent Indicator — 原理图设计与划分

> Rev 0.2 · English version: [en/04-schematic-partition.md](en/04-schematic-partition.md)
> 主板一块通吃 4 个外形方案,LED 载板(Matrix/Circle/Bar)为独立简单 PCB 经线缆接入。

## 1. 原理图页面划分(8 页)

| Sheet | 名称 | 内容 | 关键网络 |
|---|---|---|---|
| 1 | INPUT-PD | USB-C(PD) + CH224K + ESD;XT30 防反接/TVS;LM5050-1×2 ORing | VPD, VIN, VIN_SEL |
| 2 | CHARGER | MP2760 + 电感/采样电阻;S-8254A+双 NMOS;HY2213×3;电池分压采样 | VSYS, VBAT, BAT_ADC1-3 |
| 3 | DCDC | TPS56637(VLED)+ 前级 PMOS;MP2315S(5V0);TPS2121(VUSB mux);SGM2212(VDD);VAUDIO 滤波;INA226 | VLED, 5V0, 5V0_SYS, VDD, VAUDIO |
| 4 | MCU | ESP32-S3-WROOM-1-N16R8;复位/BOOT 按键;策略电阻;TCA9554 | EN, IO0, I2C_SDA/SCL |
| 5 | LCD-TOUCH | 40P FPC 座(ST7701 RGB);初始化 SPI 跳线借用 D 线;背光驱动;CST836U FPC | LCD_D0-15, PCLK, HS, VS, DE |
| 6 | LED | SN74AHCT125 电平转换 ×2 通道;VLED PMOS 开关;3×SH1.0-3P 出口 + 防护(33Ω 串阻 + ESD) | LED_M_DIN, LED_AUX_DIN |
| 7 | AUDIO | ES8311 + MEMS MIC×2(模拟差分)+ NS4150B + SPK 座;PA_EN | I2S_BCLK/WS/DO/DI |
| 8 | EXPAND | TJA1051T/3 + CAN 端子 + 终端跳线;microSD(1-bit);QMI8658C;Qwiic I2C 座;USB-C 数据口 | TWAI_TX/RX, SD_CLK/CMD/D0 |

## 2. ESP32-S3 Pinmap v0.2(ESP32-S3-DevKitC-1 N16R8)

> ⚠ **N16R8 关键约束**:GPIO26-32 = quad flash,**GPIO33-37 = octal PSRAM**,
> 全部不可用(v0.1 误把 I2S 放 33/34,v0.2 已修正)。可用普通 GPIO 仅
> 0-18、21、38-48 共 **29 个**;GPIO19/20 留作原生 USB(USB-Serial-JTAG:日志+下载+REPL)。

下表为**默认 Profile A(Display + Audio + 背光)**,DevKitC-1 物理可点亮:

| GPIO | 功能 | 网络 | 备注 |
|---|---|---|---|
| 0 | (SD_CMD)/ 备用 | — | strapping(BOOT);Profile A 不接 SD,可留按键 |
| 1 | I2S_BCLK | I2S_BCLK | ES8311 MCLK-from-SCLK 模式,省 MCLK 脚 |
| 2 | (SD_CLK)/ 备用 | — | Profile A 不接 SD |
| 3 | LCD_G4 | LCD_G4 | strapping(JTAG sel),仅作输出安全 |
| 4–7 | LCD_B0–B3 | LCD_B0..3 | |
| 8 | LCD_G3 | LCD_G3 | |
| 9–13 | LCD_R0–R4 | LCD_R0..4 | |
| 14 | LCD_PCLK | LCD_PCLK | |
| 15 | LCD_B4 | LCD_B4 | |
| 16–18 | LCD_G0–G2 | LCD_G0..2 | |
| 19/20 | USB D-/D+ | USB_DN/DP | **USB-Serial-JTAG**(日志/下载/REPL);与 TinyUSB device 互斥 |
| 21 | I2S_WS | I2S_WS | |
| 38 | I2C_SDA | I2C_SDA | CST836U/QMI8658C/TCA9554/INA226/MP2760/SHT4x/BMP280/PCF8563,4.7k 上拉 |
| 39 | I2C_SCL | I2C_SCL | |
| 40 | LED_MATRIX | LED_M_DIN | RMT CH0,经 AHCT125 |
| 41 | LED_AUX | LED_AUX_DIN | RMT CH1(circle+usage+拾音链) |
| 42 | **I2S_DOUT** | I2S_DO | → ES8311 SDIN(v0.2:原 33)。启用 SD 时此脚复用 SD_D0 |
| 43 | **LCD_BL_PWM** | BL_PWM | LEDC 背光调光 → 恒流 IC DIM 脚。启用 CAN 时复用 TWAI_TX |
| 44 | **I2S_DIN** | I2S_DI | ← ES8311 SDOUT(v0.2:原 34)。启用 CAN 时复用 TWAI_RX |
| 45 | LCD_VSYNC | LCD_VS | strapping(VDD_SPI),下拉默认即可 |
| 46 | LCD_HSYNC | LCD_HS | strapping(ROM log),仅输出 |
| 47 | LCD_DE | LCD_DE | |
| 48 | LCD_G5 | LCD_G5 | RGB565 时 G 占 6 位 |

### Profile 与功能取舍(DevKitC-1)

480×480 RGB565 屏吃掉 20 根 GPIO,叠加 I2C/LED/I2S/背光后 29 个可用脚已满,
**无法再同时上板载 SD + CAN**。固件用 Kconfig 开关:

| 功能 | Profile A(默认) | 启用方式 |
|---|---|---|
| LCD + 触摸 + I2C 传感器 | ✅ | — |
| WS2812(matrix/circle/bar) | ✅ | — |
| 音频(ES8311 全双工) | ✅ | — |
| 背光 PWM 调光 | ✅ | — |
| 板载 microSD | ❌(D0=42 与 I2S 冲突) | `CONFIG_AGENTIND_ENABLE_SD`,需禁音频或改接 |
| CAN/TWAI | ❌(43/44 与背光/I2S 冲突) | `CONFIG_AGENTIND_ENABLE_CAN`,TWAI 经 GPIO matrix 改接空脚 |

> 量产裸模组板若要全功能,需改用**串行 RGB(SPI/QSPI)屏**或加 IO 扩展/移位寄存器
> 释放数据线;DevKitC-1 原型阶段按 Profile A 验证显示+音频+灯效+传感器链路即可。

**29 个普通 GPIO 全部用满**,慢速控制走 TCA9554:

| TCA9554 | 信号 |
|---|---|
| P0 | LCD_RST |
| P1 | TP_RST(CST836U) |
| P2 | LCD_BL_EN |
| P3 | PA_EN(NS4150B) |
| P4 | LED_PWR_EN(VLED PMOS) |
| P5 | LCD_SPI_CS(ST7701 初始化 3-wire SPI,SCK/SDA 借用 LCD_PCLK 前的 D 线,初始化完成后释放) |
| P6 | CHG_INT(MP2760 中断,输入) |
| P7 | TP_INT(输入;触摸采用 20ms 轮询,INT 仅作唤醒辅助) |

I2C 地址表:CST836U 0x15 · TCA9554 0x20 · QMI8658C 0x6B · INA226 0x40 · MP2760 0x5C(待核) · 24C02(D 方案模块)0x50-0x53。

## 2.1 LCD 40P FPC 引脚定义(实物规格)

模组:ST7701 + CST836U,结构 73.03 × 76.48 × **2.34mm**,AA 70.13×70.13,SPI/RGB 双模。

| FPC 引脚 | 信号 | 接法 |
|---|---|---|
| LED_A / LED_K ×2 | 背光阳/阴极 | 经背光恒流驱动 IC(见 §2.2),非直接限流电阻 |
| GND ×3 | 地 | — |
| VCI | 面板电源 | VDD 3.3V |
| RESET | 面板复位 | TCA9554 P0(LCD_RST) |
| NC ×2 | 空 | — |
| SDA / SCK / CS | 初始化 SPI(9-bit 3-wire) | SDA←LCD_G0 网络,SCK←LCD_PCLK 网络,CS←TCA9554 P5;面板有独立 SPI 脚,无需在面板侧复用,仅 MCU 侧借 RGB 引脚 |
| PCLK / DE / VSYNC / HSYNC | RGB 时序 | GPIO14 / 47 / 45 / 46 |
| DB0–DB17 | 18-bit RGB 数据 | RGB565 接法:R4..0←DB17..13,G5..0←DB11..6,B4..0←DB5..1;**DB0、DB12 接地**(666→565 标准降位,以屏厂 datasheet 终核) |
| TP_INT / TP_SDA / TP_SCL / TP_RESET / TP_VCI | CST836U 触摸 | TCA9554 P7 / I2C_SDA / I2C_SCL / TCA9554 P1 / VDD |

## 2.2 LCD 背光恒流驱动与调光

**LED_A/LED_K 是屏内背光 LED 串的阳/阴极**(屏内已串/并好,只引出两端)。

**已确认背光规格**:**If = 80mA,Vf 典型 3.2V(Min 2.8 / Max 3.3V)**。
Vf < 5V0 → **不需要升压(boost),用低压线性恒流即可**(单串/全并联结构)。

- **方案(默认)**:**5V0 输入的低压线性恒流源**,恒流 80mA:
  - 恒流 IC 首选 **NSI45080**(定值 80mA)或 **BCR401U / AMC7140**(可设),SOT-23/89 封装,外围简单;
  - 压差 (5.0−3.2)×0.08 ≈ **0.144W** 损耗,小封装 + 铺铜即可;
  - `EN` ← TCA9554 `EXP_LCD_BL_EN`(慢速开关);`PWM/CTRL` ← MCU `GPIO43`(LEDC 2kHz PWM 调光)。
- **更省成本**:5V0 经限流电阻直驱——R ≈ (5.0−3.2)/0.08 ≈ **22Ω**,功耗 ~0.14W(0805/1206)。
  缺点:电流随 Vf/温漂变化、亮度一致性差。转接板预留 0Ω 跳线在"恒流 IC / 电阻"间二选一。
- **亮度调节**:固件 `display_set_backlight(pct)`(LEDC 8-bit duty)斩波,Lighting 页亮度滑条
  同时联动 LED 全局亮度与 LCD 背光;协议/控制台亦可驱动。
- **注意**:GPIO43 在 DevKitC-1 上原为 U0TXD;本设计日志走 USB-Serial-JTAG(GPIO19/20),
  故 43 释放给背光 PWM(见 §2 Profile A)。

## 2.3 DevKitC-1 转接板说明

原型以 **ESP32-S3-DevKitC-1(N16R8)** 插转接板实现。转接板承载:TCA9554、AHCT125
电平转换、ES8311+NS4150B 音频、背光恒流 IC、LCD 40P FPC 座、WS2812 SH1.0 出口、
Qwiic I2C(挂 IMU/SHT4x/BMP280/PCF8563)、各电源 DCDC。引脚映射见 §2,功能取舍见
§2 Profile 表——DevKitC-1 默认 Profile A(显示+音频+背光+灯+传感器),SD/CAN 需
Kconfig 开关并自行解决引脚复用。量产将转为裸模组 + §2 注释的串行屏/IO 扩展方案。

## 3. ST7701 初始化链路说明

RGB 屏需先经 3-wire 9-bit SPI 写初始化序列。借用方式(Espressif EV-Board 同款):
`SPI_SCK ← LCD_PCLK 线`、`SPI_SDA ← LCD_D0 线`、`CS ← TCA9554 P5`。
初始化阶段以 GPIO 位带模拟 SPI,完成后重配为 LCD_CAM RGB 外设。固件中对应 `display.c` 的两段初始化。

## 4. LED 载板(独立小板)

| 板 | 内容 | 接口 |
|---|---|---|
| Matrix 8×8 | 64×WS2812B,64×64mm,四角安装孔;DIN/DOUT 在两侧 2.54-3P,支持 4 块 S 形级联 | VLED/GND/DATA |
| Circle | 24×WS2812B 环形 ID75/OD85,中空走 LCD FPC | 同上 |
| Bar 系列 | 按方案选长度,统一 SH1.0-3P 双端(可续接) | 同上 |

每板 DIN 入口处:33Ω 串阻 + 1×104 每灯去耦 + 入口 220µF。

## 5. 布局分区建议(主板,估 90×70mm 四层)

```
┌─────────────────────────────────────────┐
│ [XT30][CAN] Sheet1/2 功率区  [USB-C PD] │  ← 后缘:全部对外接口
│  电感/MOS 远离 ▼               [USB-C 数据]│
│ Sheet3 DCDC ──┐   ┌─ Sheet4 MCU(天线   │
│  VLED 大电流  │   │   朝板边,净空区)   │
│ ──────────────┴───┴──────────────────── │
│ Sheet7 AUDIO(远离 DCDC)  Sheet5/6/8    │
│  MIC 走线最短             FPC/LED/SD 座 │
└─────────────────────────────────────────┘
```

- VLED 5A 路径:2oz 铜 + ≥4mm 走线宽,buck 出口直达 LED 连接器。
- Wi-Fi 天线区净空 ≥15×6mm,下方禁布。
- MIC 模拟走线包地,远离 PCLK(20MHz)与 buck 开关节点。
- RGB LCD 16 根数据线等长(±5mm 内即可,20MHz 下不敏感),整组包地。

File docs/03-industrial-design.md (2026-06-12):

# Agent Indicator — 外观与结构设计(4 方案)

> English version: [en/03-industrial-design.md](en/03-industrial-design.md)
> 3D 模型源文件与可打印 STL:[`hardware/3d/`](../hardware/3d/)(OpenSCAD)

> Rev 0.1。核心设计语言:**Halo 单元** —— LCD(AA 70.13mm 方形)沉于 LED Circle(ID75/OD85)正后方,
> 环体遮住屏幕四角(AA 对角线 99.2mm > 75mm 孔径),配合圆形 UI,视觉上呈现一块"会发光呼吸的圆屏"。
> 环到屏面留 3~4mm 段差 + 内壁哑光黑,环光不漏进屏面。

通用工艺:外壳 CNC 阳极铝或树脂 3D 打印喷砂;灯面 2mm 奶白亚克力(透光率 ~40%)做扩散,
灯珠到扩散面 ≥8mm 并加格栅(matrix 每格 8×8mm 井字格,杜绝串光);底部硅胶垫 + 配重。

---

## 方案 A 「Halo」— 圆形单体,最紧凑

只含 Halo 单元 + 底座,Usage 画在 LCD 圆形 UI 边缘弧段,Context 以圆环热力图呈现(无 Matrix)。
适合做"最小可爱款";Matrix 可后期以方案 D 模块磁吸外挂。

Halo 3D 渲染

```
        正面                          侧面
     ╭─────────╮                 ┌──┐
    ╱  ◜◝◜◝◜◝  ╲                │  │╲
   │ ◜ ╭─────╮ ◝ │               │  │ ╲  本体 Ø100×32mm
   │ ◌ │ LCD │ ◌ │ ← Circle 24LED│  │  ╲ 后仰 10°
   │ ◟ ╰─────╯ ◞ │   环绕圆形UI  ├──┴───┴──┐
    ╲  ◟◞◟◞◟◞  ╱                 │ ▂▃▅▃▂   │ ← 底座内:3×18650、
     ╰─────────╯                 └─────────┘    主板、SPK、MIC×2
      Ø100mm                      110×70×30mm   前缘拾音条 48LED@99mm
```

| 项 | 值 |
|---|---|
| 本体 | Ø100 × 32mm(环 OD85 + 7.5mm 边框) |
| 底座 | 110 × 70 × 30mm,跑道形 |
| 拾音条 | 48LED @ 99mm,嵌底座前缘斜面 |
| 电池 | 3×18650 平躺底座 |
| 体积/重量估算 | ~0.31L / ~420g(含电池) |

---

## 方案 B 「Console」— 横向一体,推荐主力款

全功能一体。左 Matrix、中竖直 Usage 条、右 Halo,底缘通长拾音条,15° 楔形坐姿。

Console 3D 渲染
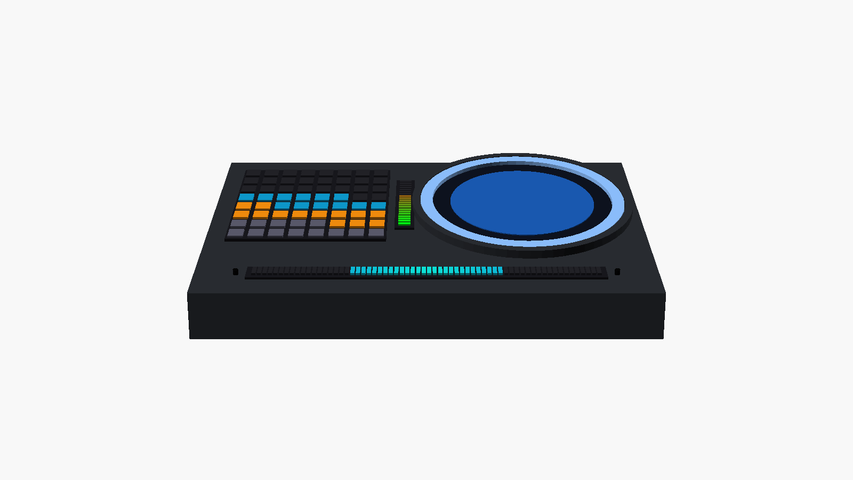
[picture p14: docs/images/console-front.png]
Console 正视


```
   ┌────────────────────────────────────────────┐
   │  ┌─────────┐  ▌   ╭───────╮                │
   │  │ ▦▦▦▦▦▦▦ │  ▌  ╱ ◜◝◜◝◜◝ ╲               │   侧视:
   │  │ ▦ 8×8 ▦ │  ▌ │ ◌ ╭───╮ ◌ │              │      ╱│
   │  │ ▦Matrix▦│  ▌ │ ◌ │LCD│ ◌ │ ← Halo Ø85   │     ╱ │ 15°楔形
   │  │ ▦▦▦▦▦▦▦ │  ▌  ╲ ◟◞◟◞◟◞ ╱               │    ╱  │ 后部高42
   │  └─────────┘  ▌   ╰───────╯                │   ╱___│ 前缘高18
   │    64mm     20LED                          │
   │ ═══════ 拾音条 64LED @132mm ═══════        │
   └────────────────────────────────────────────┘
              176 × 112 × 42mm
```

| 项 | 值 |
|---|---|
| 整机 | 176 × 112 × 42mm(后部),前缘 18mm |
| 布局 | Matrix 左(中心距左缘 42mm)· Usage 竖条居中 · Halo 右(中心距右缘 50mm) |
| 拾音条 | 64LED @ 132mm,底缘居中,MIC×2 在条两端开孔 |
| 电池 | 3×18650 横置楔形后部高区 |
| SPK | Ø28 腔体朝下,底部出音 |
| 体积/重量估算 | ~0.55L / ~580g |

16×16 升级路径:左区预留 134×134mm 可换装 4 块拼接面板(整机改 246mm 宽的 "Console XL" 外壳,内构不变)。

---

## 方案 C 「Totem」— 竖向图腾,占桌面最小

纵向叠放,正投影仅 78×62mm。从上到下:Halo → Matrix → 底座;Usage 竖条贴右侧棱,拾音条嵌底座前缘。

```
      ┌──────────┐
      │ ╭──────╮ │
      │ │ Halo │ │  Ø85 → 段宽 90
      │ ╰──────╯ │
      ├──────────┤▌
      │ ▦▦▦▦▦▦▦▦ │▌← Usage 20LED
      │ ▦ 8×8  ▦ │▌   贴右棱竖排
      │ ▦▦▦▦▦▦▦▦ │▌
      ├──────────┤
      │ ▂▃▅▆▅▃▂  │ ← 底座:电池+主板+SPK
      └──────────┘    前缘拾音条 20LED@41.5mm
       78 × 240(高) × 62mm,底座配重 150g
```

| 项 | 值 |
|---|---|
| 整机 | 78 × 240 × 62mm(底座深 90mm 防倾倒) |
| 拾音条 | 20LED @ 41.5mm(底座宽度限制) |
| 电池 | 3×18650 竖置底座 |
| 特点 | 桌面占地最小;Halo 在视线高度;IMU 检测倾倒自动断 VLED |

---

## 方案 D 「Tiles」— 磁吸模块系统,可玩性最高

统一 **90×90×22mm** 模块外框(容纳最大件:Ring OD85 / LCD 76.48),四边中点磁吸 + 4P pogo
(VLED / GND / DATA-IN / DATA-OUT),底部燕尾槽卡入供电轨。Matrix 模块 2×2 拼即得 16×16。

```
  ┌────────┐ ┌────────┐ ┌────────┐ ┌────────┐
  │ ╭────╮ │ │ ▦▦▦▦▦▦ │ │   ▌    │ │ ◌◌◌◌◌◌ │
  │ │Halo│ │ │ ▦ 8×8▦ │ │   ▌Bar │ │ ◌ 空白◌│  ← 模块家族:
  │ ╰────╯ │ │ ▦▦▦▦▦▦ │ │   ▌    │ │ ◌(扩展)│    Halo / Matrix / Bar / 自定义
  └──┬─┬───┘ └──┬─┬───┘ └──┬─┬───┘ └──┬─┬───┘
  ═══╧═╧════════╧═╧════════╧═╧════════╧═╧══════  ← Dock 供电轨 370×60×26mm
  │ ▂▃▅ 拾音条 80LED@164.7mm ▅▃▂   [主机区] │     内置:主板+电池+SPK+MIC
  ╚═══════════════════════════════════════════╝     右端主机区出 USB-C/XT30/CAN
```

Tiles 3D 渲染

| 项 | 值 |
|---|---|
| 模块 | 90 × 90 × 22mm,磁吸力 ~0.8kg(Ø8×3 钕磁 ×4) |
| Dock | 370 × 60 × 26mm(4 模块位),或 190mm 双位短轨 |
| 拾音条 | 80LED @ 164.7mm 嵌 Dock 前缘(短轨用 48LED@99mm) |
| 电气 | 轨内 VLED 总线 + WS2812 数据菊花链经 pogo 串行流过各模块;模块内 EEPROM(24C02)存类型 ID,主机上电枚举排序 |
| 16×16 | 4 个 Matrix 模块 2×2 离轨磁吸拼接,边缘 pogo S 形跳数据,整体再以 1 个轨位接入 |

---

## 方案 E 「Soundbar」— 显示器下横条

塞进显示器支架下方缝隙,正面 12° 后仰全部朝向用户:左 8×8 Matrix(48mm 紧凑灯距),
中央 Halo(縮小版 Ø47 环 + 圆屏,可换 1.28" 圆屏模组),右水平 Usage 条,
底缘 **160LED@329mm 全宽拾音条** —— 桌面最自然的常驻位置。

Soundbar 3D 渲染

| 项 | 值 |
|---|---|
| 整机 | 340 × 58 × 54mm,前面板 12° 后仰 |
| 拾音条 | 160LED @ 329mm(产品线中最长,VU 效果最佳) |
| 显示 | 中央 Halo 用 1.28" 圆屏(GC9A01)替代方形屏,环径缩至 Ø47 |
| 电池 | 2×18650(高度受限),或纯 USB-PD 供电去电池 |
| 备注 | MIC×2 在条两端,远离显示器扬声器干扰区 |

## 方案 F 「Orb」— 球形桌宠

Ø110 球体正面切平嵌 Halo,底环透出氛围光,12° 仰角望向用户。
只保留 Status + I/O(无 Matrix/Usage,信息走屏幕圆形 UI),情感化最强、
零件最少的"桌宠"形态;底座氛围环复用 Circle 灯板。

Orb 3D 渲染

| 项 | 值 |
|---|---|
| 整机 | Ø110 球体 + Ø96 配重座,总高 ~135mm |
| 灯 | 正面 Circle 24LED + 底环氛围光(共两路 Circle 灯板) |
| 电池 | 1×18650 居中配重,或 21700 |
| 备注 | IMU 敲击 = 确认交互;球壳两半 CNC/打印后胶合,赤道分缝 |

## 方案对比与建议

| | A Halo | B Console | C Totem | D Tiles | E Soundbar | F Orb |
|---|---|---|---|---|---|---|
| 功能完整度 | ◐(无 Matrix) | ● | ● | ●+ | ● | ◔(仅 Status+IO) |
| 紧凑/精致 | ●● | ● | ●(占地最小) | ◐(轨道偏长) | ●(藏屏下) | ●●(桌宠) |
| 结构难度 | 低 | 中 | 中 | 高(pogo/磁吸/枚举) | 中 | 中(球壳分缝) |
| 16×16 扩展 | 外挂 | 换壳 | 不支持 | 原生 | 不支持 | 不支持 |
| 建议定位 | 入门款/礼品 | **主力款,先做** | 衍生款 | 旗舰款,二期 | 工位常驻款 | 情感化衍生款 |

**建议路线**:先出 B(Console)验证全部电路与固件 → 复用 Halo 单元出 A → 二期做 D 的 Dock 与模块化结构。
四个方案共用同一块主板(见 04 文档),仅外壳与 LED 载板不同。

待确认尺寸(我按常规估的,如有实物请修正):
1. 18650 含保护板长度按 65mm(无保护)算,支架外廓 58×78mm;
2. Matrix 灯板厚度按 PCB 1.6mm + 灯珠 2.5mm 算;
3. ~~LCD 模组总厚按 3.5mm(含 CTP)算~~ 已确认:**2.34mm**(73.03×76.48×2.34 实物规格)。

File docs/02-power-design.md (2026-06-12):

# Agent Indicator — 电源方案设计

> Rev 0.2 · English version: [en/02-power-design.md](en/02-power-design.md) · 配套 [01-system-design.md](01-system-design.md)

## 1. 电源拓扑

```
USB-C PD ──► CH224K ──► VPD(15V≥3A) ──► 理想二极管 ─┐
  (诱骗15V)                            (LM5050-1+PFET)│
                                                      ├──► VIN_SEL ──► MP2760 ──► VSYS(9~12.6V)
XT30 ──► 防反接PFET+TVS ──► VIN(12-24V) ─► 理想二极管 ─┘            (NVDC buck-boost   │
                                          (优先级高)                 充电器+电源路径)   │
                                                                        ▲▼              │
                                            3S 18650 ◄── S-8254A 保护 ──┘               │
                                            (11.1-12.6V)  HY2213×3 均衡                 │
                                                                                        │
        ┌───────────────────────────────────────────────────────────────────────────────┤
        │                                     │                                         │
   TPS56637                               MP2315S                                       │
   VLED 5.0V/5A ──► PMOS开关(LED_PWR_EN)  5V0 2A ──┬─► TPS2121 ◄── VUSB(USB-C 数据口VBUS)
   ──► WS2812B Matrix/Ring/Bars                    │   (无缝切换+防倒灌,USB可单独点亮逻辑)
                                                   ├─► SGM2212-3.3 ──► VDD 3.3V
                                                   │    (SD卡/IMU/Codec逻辑/扩展I2C)
                                                   └─► 磁珠+钽电容 ──► VAUDIO 5V(NS4150B)
```

要点:
- **MP2760 NVDC 电源路径**:输入在位时系统由输入供电并给电池充电,输入移除瞬时无缝切到电池,无需额外切换电路。
- **输入优先级**:XT30 与 VPD 经理想二极管 ORing。XT30 支路加 30mV 偏置使同压时 XT30 优先;PD 仅 15V、XT30 24V 时自然高压优先。
- **VLED 与 5V0 隔离**:两路独立 buck,LED 大电流纹波不串入逻辑电源;USB 数据口 VBUS 经 TPS2121 与 5V0 互为备份且互不倒灌(拔掉主电源时插 USB 仍可调试,LED 不上电)。

## 2. 器件选型

| 节点 | 器件 | 关键参数 | 说明 |
|---|---|---|---|
| PD 诱骗 | **CH224K** | 申请 15V(CFG 配置),100W 级 | 15V > 12.6V+充电裕量,满足 buck-boost 全范围;LED 脚指示 PD 成功 |
| 输入 ORing | **LM5050-1** ×2 + PFET(如 AO4407A) | 理想二极管控制器 | 也可用集成款(如 LM74700) |
| XT30 防反/浪涌 | PFET 防反接 + **SMBJ26A** TVS + NTC | 24V 输入 | XT30 旁出 CAN 4P 端子(CANH/L/12V/GND) |
| 充电器 | **MP2760** | 1-4S NVDC buck-boost,I2C,输入 2.7-22V,充电 ≤6A | 12V XT30 / 15V PD 都能给 3S 充满;I2C 上报状态;备选 BQ25756(控制器+外置管,功率更大) |
| 电池保护 | **S-8254A** + 双 NMOS(共漏) | 3S 过充/过放/过流/短路 | 经典方案;备选 BQ76905(带库仑计) |
| 均衡 | **HY2213-BB3A** ×3 | 单节 4.2V 旁路均衡 66mA | 每节并联,简单可靠的充电末端均衡 |
| 电池监测 | 3 节分压 → MCU ADC + **INA226**(VSYS 高侧) | — | SOC 估算 + 功耗遥测 |
| VLED buck | **TPS56637** | 4.5-28V 输入,6A,固定 5V 可调 | 输出 5.0V,布局靠近 LED 接口;前级 PMOS 受 LED_PWR_EN 控制 |
| 5V0 buck | **MP2315S** | 4.5-24V,3A | 给开发板/逻辑/音频 |
| USB 防倒灌 | **TPS2121** | 双输入功率 mux,无缝切换 | 5V0(优先)vs VUSB;输出 5V0_SYS |
| VDD LDO | **SGM2212-3.3** | 1A,低压差 | SD 卡峰值 ~200mA + 外设充裕 |
| VAUDIO | 磁珠 + 220µF | 自 5V0_SYS 滤波 | NS4150B 3W 突发电流去耦 |

## 3. 功耗预算

WS2812B 按实测典型 16mA/通道(5V 折算 240mW/颗全白)计;固件全局限流到 VLED 4.5A。

| 负载 | 数量 | 典型(动画 25% 亮度) | 峰值(全白) |
|---|---|---|---|
| Matrix 8×8 | 64 | 0.77A | 3.07A |
| Matrix 16×16(扩展) | 256 | 3.07A | 12.3A → 固件限流 |
| Circle | 24 | 0.29A | 1.15A |
| Usage bar 20 + 拾音条 64 | 84 | 1.0A | 4.0A |
| **VLED 合计(8×8 配置)** | 172 | **~2.1A / 10.4W** | 限流 4.5A / 22.5W |
| LCD(屏+背光) | — | 1.2W | 1.5W |
| ESP32-S3(Wi-Fi 活动) | — | 0.8W | 1.7W(峰值) |
| 音频(3W PA 突发) | — | 0.2W | 3W |
| **系统合计** | — | **~14W** | ~29W |

- PD 15V×3A=45W:供整机峰值 + 约 1A 充电电流,够用;XT30 24V 时充电可放开到 2A。
- 续航估算:3S×3000mAh≈33Wh,典型 14W → **~2.3h**;待机模式(LED 断电、LCD 低亮)<1.5W → >20h。
- 16×16 扩展:建议外接 XT30 供电使用,VLED 限流策略将全白场景压到 4.5A(平均亮度 ~35%),如需更高可并联第二片 TPS56637(预留焊位)。

## 4. 保护与细节

1. **过充/过放**:S-8254A 阈值 4.25V/2.7V 每节;MP2760 充电终止 12.6V、截止电流 C/10。
2. **平衡充**:HY2213 在任一节到 4.2V 时旁路 66mA,配合 MP2760 末端小电流完成均衡。
3. **防倒灌**:USB VBUS 仅进 TPS2121,永不反灌;VPD/VIN 理想二极管单向;VLED 关断 PMOS 防 LED 灯板反向漏电。
4. **浪涌/ESD**:XT30 进口 TVS;USB-C 两口 USBLC6-2SC6;CAN 口 PESD1CAN。
5. **热设计**:TPS56637 大面积铺铜 + 过孔阵;MP2760 充电 2A 时 ~1W 损耗,同样处理。
6. **上电时序**:VDD 先于 LED_PWR_EN/BL_EN(由固件经 TCA9554 延时使能),避免 WS2812 上电窜亮。
7. **采样**:3 节电池分压经 100k/10k + RC 进 ADC(经保护板前的均衡抽头),静态泄放 <15µA。

## 5. 连接器定义

| 接口 | 连接器 | 引脚 |
|---|---|---|
| PD 输入 | USB-C 16P(仅 PD) | CC 接 CH224K |
| 数据 USB | USB-C 16P | D+/D- → GPIO19/20,VBUS → TPS2121 |
| 外部电源 | XT30-M | 12-24V |
| CAN | XH2.54-4P | 12V / CANH / CANL / GND(末端 120Ω 跳线) |
| 电池 | XH2.54-4P(B-,B1,B2,B+) | 平衡线全引出 |
| LED 各路 | SH1.0-3P ×3 | VLED / DIN / GND(Matrix 板间 2.54 排针级联) |
| 扩展 I2C | SH1.0-4P(Qwiic 兼容) | 3V3 / GND / SDA / SCL |

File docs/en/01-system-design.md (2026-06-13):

# Agent Indicator — System Design Overview

> LLM status indicator desk gadget · Rev 0.2 · 2026-06
> 中文版:[../01-system-design.md](../01-system-design.md)
> Companion docs: [02-power-design.md](02-power-design.md) Power · [03-industrial-design.md](03-industrial-design.md) Industrial design · [04-schematic-partition.md](04-schematic-partition.md) Schematics

## 1. Feature Definition

| Feature | Carrier | Description |
|---|---|---|
| LLM usage display | RGB Bar (20-LED vertical, segmented) | Multi-slot percentage bars: session usage, 5h/weekly limits |
| LLM status display | RGB Circle (24 LEDs) | Animations for idle / thinking / responding / tool-use / error |
| LLM context display | RGB Matrix (8×8; firmware supports 4 tiles as 16×16) | Context-window heat map / category color blocks |
| LLM input/output | LCD (ST7701 480×480 + CST836U touch) | Scrolling prompt/response digest, touch paging |
| Mic level | RGB Bar (long horizontal) | Local mic VU meter / tone visualization |
| Tones / voice pickup | I2S codec + PA + MEMS mic | Task-done chimes, voice input level |

Expansion interfaces: SDMMC (assets/recordings), CAN/TWAI (bus access), USB Device (custom EP + CDC), I2C (touch + sensors).

## 2. System Block Diagram

```
                        ┌────────────────────────────────────────────┐
   Linux PC (Host)      │              Agent Indicator               │
  ┌──────────────┐      │  ┌──────────────────────────────────────┐  │
  │ agentind     │ WiFi │  │           ESP32-S3-WROOM-1-N16R8     │  │
  │ (Python      │◄────►│  │                                      │  │
  │  bridge)     │ CAN  │  │ RGB-LCD16bit ──► ST7701 480×480 LCD  │  │
  │  - sources   │◄────►│  │ I2C ──► CST836U / QMI8658C / TCA9554  │  │
  │  - protocol  │ USB  │  │            / INA226 / MP2760         │  │
  │  - transports│◄────►│  │ RMT×2 ──► WS2812B Matrix / Ring+Bars │  │
  └──────────────┘      │  │ I2S ──► ES8311 ──► NS4150B ──► SPK   │  │
                        │  │              ▲MIC                    │  │
                        │  │ SDMMC 1-bit ──► microSD              │  │
                        │  │ TWAI ──► TJA1051T/3 ──► CAN          │  │
                        │  │ USB-OTG ──► Type-C (data, separate   │  │
                        │  │             from the PD port)        │  │
                        │  └──────────────────────────────────────┘  │
                        │  Power: PD(15V) / XT30(12-24V) / 3S 18650  │
                        └────────────────────────────────────────────┘
```

## 3. Component Selection

### 3.1 Main Controller

| Item | Choice | Rationale |
|---|---|---|
| MCU module | **ESP32-S3-WROOM-1-N16R8** | 16MB flash + 8MB octal PSRAM. The 480×480×RGB565 frame buffer (~460KB) must live in PSRAM; LCD_CAM drives the RGB panel directly; native USB-OTG; TWAI; RMT for WS2812; Wi-Fi |

Note: octal PSRAM on the N16R8 occupies GPIO35/36/37 — see the pinmap in doc 04.

### 3.2 Peripheral ICs

| Function | Choice | Alternative | Notes |
|---|---|---|---|
| CAN transceiver | **TJA1051T/3** | SIT1051T | /3 variant has 3.3V VIO, no level shifting; 5V from 5V0 |
| Audio codec | **ES8311** (default) / **WM8960** (also supported) | ES8388 | Firmware auto-detects by I2C address at runtime: ES8311@0x18 (mono, BCLK-as-MCLK saves a GPIO) / WM8960@0x1A (stereo, **needs MCLK** on `BOARD_I2S_MCLK`). Same pinout, populate either |
| Audio PA | **NS4150B** | MAX98357 (pure I2S) | 3W class-D, same pairing as Espressif dev boards; EN on the IO expander |
| MIC | **MSM261 (analog MEMS) → ES8311 MIC_IN** | INMP441 (I2S digital) | Analog input via codec saves I2S lines; VU computed in firmware (RMS) |
| IMU | **QMI8658C** | LSM6DS3TR-C | 6-axis, I2C, tap/raise interrupts; cheap and well documented; used for tap interaction and orientation flip |
| Touch | **CST836U** (with panel) | — | I2C 0x15, same protocol family as CST816, works with `esp_lcd_touch_cst816s` |
| IO expander | **TCA9554** | PCA9554 | LCD_RST / TP_RST / PA_EN / BL_EN / LED_PWR_EN and other slow controls; relieves GPIO pressure |
| Current monitor | **INA226** | INA219 | High-side on VSYS; battery/power telemetry |
| LED level shifter | **SN74AHCT125** | 74HCT245 | 3.3V→5V data; WS2812B at 5V needs VIH=3.5V, shifting is mandatory |

Power-chain parts (CH224K / MP2760 / S-8254A / HY2213 / TPS56637 / MP2315S / TPS2121 / SGM2212): see [02-power-design.md](02-power-design.md).

### 3.3 Display & LEDs

| Item | Parameters |
|---|---|
| LCD | ST7701S, 480×480, 16-bit RGB565 parallel + 3-wire SPI init (SPI lines borrowed from RGB data lines, same trick as Espressif reference designs); outline 73.03×76.48mm, AA 70.13×70.13mm |
| RGB Matrix | WS2812B 8×8, 64×64mm, board-to-board/cable cascade; firmware supports 1 or 4 tiles (16×16), configurable serpentine scan |
| RGB Circle | WS2812B ×24, ID 75 / OD 85mm |
| RGB Bar | Length per enclosure variant: usage 20LED@41.5mm vertical; mic bar 48LED@99mm or 64LED@132mm (see doc 03) |

## 4. Module Design

### 4.1 LED subsystem

- **Driver**: RMT ×2 channels (`led_strip` component, DMA).
  - CH0 `LED_MATRIX`: matrix chain (1–4 tiles, 64–256 px).
  - CH1 `LED_AUX`: circle(24) → usage bar(20) → mic bar(48/64), one chain with logical segments.
- **Refresh**: 60 fps animation engine; a 172-LED chain @800kHz ≈ 5.2ms, ample headroom.
- **Current limiting**: firmware global limiter — sums theoretical current per frame (16mA per channel), scales the whole frame down when over the VLED budget (4.5A). Essential for 16×16.
- **Power**: VLED 5V/5A, LED_PWR_EN (TCA9554) gates a PMOS; fully unpowered in sleep.

### 4.2 LCD subsystem

- `esp_lcd` RGB panel + `esp_lcd_st7701` (managed component), dual bounce buffers against PSRAM bandwidth jitter; PCLK from 20MHz.
- LVGL 9 (`esp_lvgl_port`): I/O text stream page, status page, settings; CST836U swipe paging.
- Backlight: BL_EN (TCA9554) on/off + content-adaptive dimming; hardware PWM dimming possible by sacrificing TWAI_TX (noted in pinmap).

### 4.3 Audio subsystem

- ES8311: I2S slave, internal MCLK from BCLK ("MCLK from SCLK" mode), 16kHz/16-bit capture, 44.1kHz tone playback.
- Tones: WAV from SD or embedded in flash.
- Mic bar: 20ms-window RMS → dB → gradient on the mic bar, closed loop on-device.

### 4.4 Communication subsystem (three links, one protocol layer)

| Link | Implementation | Scenario |
|---|---|---|
| Wi-Fi | Device runs a WebSocket server (`esp_http_server`) + mDNS `_agentind._tcp`; the PC acts as AP, host discovers via zeroconf and connects | Primary link, wireless desk placement |
| CAN | TWAI 500kbps, 11-bit IDs, light segmentation for >8B (see §5.3); PC side USB-CAN + SocketCAN | Industrial / multi-device bus |
| USB | TinyUSB composite: vendor-class bulk EP (protocol frames) + CDC (logs) | Zero-config direct attach, firmware debug |

All three links listen simultaneously; the most recently active link gets telemetry replies.

### 4.5 Power management

- MP2760 (I2C) + INA226 + 3-cell voltage sense → SoC estimation, charge state; low battery = red breathing on the circle edge.
- Idle 5min: LCD dims, LEDs drop to a breathing standby; 30min: VLED off, LCD sleep, wake on touch/IMU tap.

## 5. Protocol (host ↔ device)

### 5.1 Frame format (WS / USB / CDC)

```
┌──────┬─────┬──────┬──────┬─────────┬─────────┬───────┐
│ 0xA9 │ VER │ TYPE │ FLAGS│ LEN(LE) │ PAYLOAD │ CRC16 │
│  1B  │ 1B  │  1B  │  1B  │   2B    │  ≤512B  │  2B   │
└──────┴─────┴──────┴──────┴─────────┴─────────┴───────┘
```
- VER=0x01; CRC16-CCITT over VER..PAYLOAD; one message per WS binary frame.

### 5.2 Message types

| TYPE | Dir | Name | Payload |
|---|---|---|---|
| 0x01 | H→D | STATE | `u8 state, u8 detail`. state: 0 IDLE / 1 CONNECTING / 2 THINKING / 3 RESPONDING / 4 TOOL_USE / 5 WAITING_USER / 6 ERROR / 7 RATE_LIMITED / 8 OFFLINE |
| 0x02 | H→D | USAGE | `u8 n, n×{u8 slot, u8 percent}`. slot: 0 session / 1 5h limit / 2 weekly / 3 cost |
| 0x03 | H→D | CONTEXT | `u32 used, u32 total, u8 n, n×{u8 category, u32 tokens}`. category: system/tools/mcp/memory/messages/free |
| 0x04 | H→D | TEXT | `u8 stream(0 in/1 out), u8 op(0 append/1 replace/2 clear), utf8[]` |
| 0x05 | H→D | TONE | `u8 tone_id` (0 done / 1 attention / 2 error / 3 boot) |
| 0x06 | H→D | CONFIG | `u8 key, u32 value`. key: 0 brightness / 1 matrix tiles (1\|4) / 2 orientation / 3 UI language (0 en, 1 zh) / 4 light fx ([15:8]=mode 0-5, [7:0]=speed) / 5 fx color 0xRRGGBB (send before key=4) |
| 0x80 | D→H | TELEMETRY | `u16 vbat_mV ×3cell, i16 ibat_mA, u8 soc, u8 chg_state, u8 src(0 bat/1 pd/2 xt30)` |
| 0x81 | D→H | INPUT | `u8 kind(0 touch/1 imu_tap/2 imu_shake), u8 arg` |
| 0x82 | D→H | MIC_LEVEL | `u8 db` (optional subscription) |

### 5.3 CAN mapping

11-bit ID = `0x500 | TYPE & 0x1F`; payloads >7B are segmented: `byte0 = (seq<<4)|total`, first segment's byte1 is the original TYPE. TELEMETRY goes out as a single frame at `0x580`.

## 6. Software Deliverables

```
host/      Python package agentind: sources (Claude Code hooks/JSONL) → protocol → ws/can/usb
firmware/  ESP-IDF v5.2: comm (3 links) / proto / ui (matrix·ring·bar·lcd) / audio / power
           + storage (SPIFFS/SD) / console (test REPL) / cases (CAN·audio·IMU tests)
```

See each directory's README.

## 7. Firmware Platform Capabilities (added in v0.2)

| Capability | Implementation | Notes |
|---|---|---|
| File systems | SPIFFS (6MB `storage` partition → `/spiffs`) + microSD (1-bit SDMMC → `/sdcard`, hot-mountable) | LVGL accesses both via `LV_USE_FS_POSIX` drive letter `A:` |
| Vector fonts | LVGL TinyTTF (stb_truetype-based, **not FreeType**) | Auto-loads `/spiffs/fonts/ui.ttf` at boot; supports .ttf and .otf with TrueType outlines, **not CFF/PostScript .otf**, no hinting/kerning. For full OTF switch to `lv_freetype` + FreeType (~+600KB) |
| UI i18n | zh/en string tables in `ui/i18n.c`, persisted in NVS | Switch via console `lang zh\|en` or protocol CONFIG key=3; Chinese rendering requires a CJK TTF (built-in Montserrat has no CJK glyphs) |
| LVGL | LVGL9 + esp_lvgl_port, dual FB direct mode + bounce buffer anti-tearing | LVGL task stack 10KB (TinyTTF rasterization runs there) |
| Test console | esp_console REPL @ USB Serial/JTAG | Mutually exclusive with the TinyUSB vendor EP (same USB PHY); pick one for production |
| Test cases | CAN tx/rx; audio rec/replay/player-from-SD/rec-to-SD/loopback; IMU visualization | C++ (`cases/`), command list in firmware/README; degrades to log mode without LCD/peripherals |
| C++ support | New modules in C++17, `extern "C"` interop with the C framework | Explicit task stacks: LVGL 10K / REPL 8K / player 8K / capture 6K / imu_vis 6K / CAN 4K |

### 7.1 Audio data-flow design

A single capture task owns I2S RX: it always computes the VU level (mic bar), and
dispatches the same stream to recording (RAM/SD) or loopback depending on mode; the
TX side is serialized by a mutex (tone / player / loopback never run concurrently),
avoiding multi-task contention over I2S handles.

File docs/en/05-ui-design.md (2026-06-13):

# Agent Indicator — On-screen UI Design

> Rev 0.1 · 中文版: [../05-ui-design.md](../05-ui-design.md)
> Screenshots are produced by `tools/ui_sim` (headless LVGL on PC) and are
> pixel-identical to the firmware rendering — both compile the same sources
> in `firmware/main/ui/screens/`.

**⚠ Round-screen layout**: the LCD is a **480×480 circular** active area (the inscribed
circle; corners are invisible), so the UI **does not use lv_tabview** (its full-width tab
bar and edge-hugging card corners would be clipped). Instead:

- content is confined to a **centered safe area** (320×300, inside the R240 circle), with a
  66px margin at the top;
- navigation is a **bottom-centered pill** (290 wide, within the bottom chord), 6 icons;
- screenshots are masked to a circle to show the real visible area (outside = bezel).

All data-update entry points (`ui_*_set`) are internally locked and callable from any
task; Light/Dark themes are supported (§7).

## 1. Home — status & I/O stream

Home

- Top bar: state color dot + state name (follows i18n language) + context arc (`128k`);
- Two usage bars: session (blue) / 5h limit (orange), fed by USAGE messages;
- Below: the LLM input/output text stream (TEXT messages, 4KB scrollback).

## 2. Lighting — LED effects (OpenRGB-style presets)

Lighting

- Modes: **Agent** (default state-driven) / **Solid** / **Breath** /
  **Marquee** / **Rainbow** / **Off**;
- RGB sliders + live preview swatch; Speed (1-100) and global brightness;
- Equivalent controls: console `light <mode> [RRGGBB] [speed]`, protocol CONFIG key=4/5;
- Override effects treat matrix+circle+bars as one logical strip; the current
  limiter still applies.

## 3. Wi-Fi — connection management

Wi-Fi

- Status row (connected IP / disconnected) + Scan button (async esp_wifi scan);
- Network list (RSSI + lock mark); tapping pops a full-screen password keyboard,
  then `esp_wifi_set_config` persists to NVS and reconnects.

## 4. Devices — sensor & peripheral detection (= settings page)

Devices

Four zones, top to bottom:

1. **Environment card**: temperature ℃ / humidity % / pressure hPa (SHT4x + BMP280) + RTC clock, 500ms refresh;
2. **Presence table** (scrollable, 11 rows): green = present / red = missing, right column shows I2C address or status. Probed once at boot via `sensors_init` + `i2c_probe`:

   | Device | Addr | Note |
   |---|---|---|
   | TCA9554 IO expander | 0x20 | slow-control expander |
   | CST836U touch | 0x15 | cap touch |
   | QMI8658C IMU | 0x6B | 6-axis |
   | Audio codec | ES8311/WM8960 | I2S + I2C, auto-detected |
   | INA226 monitor | 0x40 | power telemetry |
   | MP2760 charger | 0x5C | charging |
   | microSD | — | SDMMC mount state |
   | CAN bus | 500k | TWAI |
   | **SHT4x temp/humi** | **0x44** | **temp/humidity sensor** |
   | **BMP280 pressure** | **0x76** | **barometer (SDO=GND; 0x77=SDO=VDD)** |
   | **PCF8563 RTC** | **0x51** | **I2C real-time clock** |

3. **Live IMU row**: 6-axis accel + temperature, 500ms refresh;
4. **Power row + theme switch**: V/I/SoC, with a Light/Dark switch on the right (see §7).

The three new I2C environment drivers live in `firmware/main/drivers/sensors.cpp`: SHT4x
(0xFD high-precision), BMP280 (calibration + Bosch fixed-point compensation), PCF8563
(BCD time registers). When absent each `*_present()` returns false and the row shows red.
They share the I2C bus (plug into the Qwiic connector).

## 5. Files — file browser

Files

- Backed by LVGL FS (drive `A:` = POSIX VFS); browses `/spiffs` and `/sdcard`;
- Tap to enter directories, `..` to go up, circular-scrolling path bar.

## 6. Music — player

Music

- Track info + progress + transport (prev/play/next) + volume arc (codec DAC);
- Backend is `audio_player` (WAV from SD); playlist glue marked TODO.

## 7. Light / Dark theme

The whole UI supports light/dark themes, toggled by the switch at the bottom-right of
the Devices page and **persisted in NVS**. Implementation: `screens.c` keeps two palette
token sets (`t_bg/t_card/t_text/t_sub/t_area`); switching re-runs `lv_theme_default_init`
(built-in widgets) + rebuilds the UI from tokens, then calls the `on_rebuild` host
callback to re-populate data. Can also be driven by protocol/console.

| Dark (default) | Light |
|---|---|
| Home dark | Home light |
| Devices dark | Devices light |

## Simulator usage

```bash
cd tools/ui_sim
cmake -B build && cmake --build build -j   # reuses LVGL from firmware managed_components
./build/ui_sim shots/                      # writes ui-*.bmp (dark) + ui-light-*.bmp (light), 12 total
```

Note: LVGL must use CLIB malloc (`CONFIG_LV_USE_CLIB_MALLOC` in firmware,
`LV_USE_STDLIB_MALLOC=LV_STDLIB_CLIB` in the simulator) — the built-in 64KB
TLSF pool can't hold six pages of widgets and OOM ends in an infinite loop
inside `lv_obj_add_style`.

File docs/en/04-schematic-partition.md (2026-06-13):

# Agent Indicator — Schematic Design & Partitioning

> Rev 0.2 · 中文版: [../04-schematic-partition.md](../04-schematic-partition.md)
> One main board serves all four enclosure variants; LED carriers (matrix/circle/bar) are simple separate PCBs on cables.

## 1. Schematic Sheets (8)

| Sheet | Name | Contents | Key nets |
|---|---|---|---|
| 1 | INPUT-PD | USB-C (PD) + CH224K + ESD; XT30 reverse protection/TVS; LM5050-1×2 ORing | VPD, VIN, VIN_SEL |
| 2 | CHARGER | MP2760 + inductor/sense; S-8254A + dual NMOS; HY2213×3; cell dividers | VSYS, VBAT, BAT_ADC1-3 |
| 3 | DCDC | TPS56637 (VLED) + PMOS; MP2315S (5V0); TPS2121 (VUSB mux); SGM2212 (VDD); VAUDIO filter; INA226 | VLED, 5V0, 5V0_SYS, VDD, VAUDIO |
| 4 | MCU | ESP32-S3-WROOM-1-N16R8; reset/BOOT buttons; strapping; TCA9554 | EN, IO0, I2C_SDA/SCL |
| 5 | LCD-TOUCH | 40P FPC (ST7701 RGB); init-SPI sharing jumpers; backlight driver; CST836U FPC | LCD_D0-15, PCLK, HS, VS, DE |
| 6 | LED | SN74AHCT125 ×2 channels; VLED PMOS switch; 3× SH1.0-3P with 33Ω series + ESD | LED_M_DIN, LED_AUX_DIN |
| 7 | AUDIO | ES8311 + MEMS mics ×2 (analog diff) + NS4150B + SPK; PA_EN | I2S_BCLK/WS/DO/DI |
| 8 | EXPAND | TJA1051T/3 + CAN header + term jumper; microSD (1-bit); QMI8658C; Qwiic; USB-C data | TWAI_TX/RX, SD_CLK/CMD/D0 |

## 2. ESP32-S3 Pinmap v0.2 (ESP32-S3-DevKitC-1 N16R8)

> ⚠ **N16R8 constraint**: GPIO26-32 = quad flash, **GPIO33-37 = octal PSRAM**,
> all unusable (v0.1 wrongly placed I2S on 33/34, fixed in v0.2). Only 0-18, 21,
> 38-48 (**29 pins**) are free; GPIO19/20 are kept for native USB (USB-Serial-JTAG:
> log + flashing + REPL).

Table below is the default **Profile A (Display + Audio + Backlight)**, physically
bring-up-able on DevKitC-1:

| GPIO | Function | Net | Notes |
|---|---|---|---|
| 0 | (SD_CMD) / spare | — | strapping (BOOT); no SD in Profile A |
| 1 | I2S_BCLK | I2S_BCLK | ES8311 MCLK-from-SCLK mode saves the MCLK pin |
| 2 | (SD_CLK) / spare | — | no SD in Profile A |
| 3 | LCD_G4 | LCD_G4 | strapping (JTAG sel), output-only is safe |
| 4–7 | LCD_B0–B3 | LCD_B0..3 | |
| 8 | LCD_G3 | LCD_G3 | |
| 9–13 | LCD_R0–R4 | LCD_R0..4 | |
| 14 | LCD_PCLK | LCD_PCLK | |
| 15 | LCD_B4 | LCD_B4 | |
| 16–18 | LCD_G0–G2 | LCD_G0..2 | |
| 19/20 | USB D-/D+ | USB_DN/DP | **USB-Serial-JTAG** (log/flash/REPL); exclusive with TinyUSB device |
| 21 | I2S_WS | I2S_WS | |
| 38 | I2C_SDA | I2C_SDA | CST836U/QMI8658C/TCA9554/INA226/MP2760/SHT4x/BMP280/PCF8563, 4.7k pull-ups |
| 39 | I2C_SCL | I2C_SCL | |
| 40 | LED_MATRIX | LED_M_DIN | RMT CH0 via AHCT125 |
| 41 | LED_AUX | LED_AUX_DIN | RMT CH1 (circle+usage+mic chain) |
| 42 | **I2S_DOUT** | I2S_DO | → ES8311 SDIN (v0.2: was 33). Shares SD_D0 if SD enabled |
| 43 | **LCD_BL_PWM** | BL_PWM | LEDC backlight dimming → constant-current IC DIM. Shares TWAI_TX if CAN enabled |
| 44 | **I2S_DIN** | I2S_DI | ← ES8311 SDOUT (v0.2: was 34). Shares TWAI_RX if CAN enabled |
| 45 | LCD_VSYNC | LCD_VS | strapping (VDD_SPI), default pull-down is fine |
| 46 | LCD_HSYNC | LCD_HS | strapping (ROM log), output only |
| 47 | LCD_DE | LCD_DE | |
| 48 | LCD_G5 | LCD_G5 | G uses 6 bits in RGB565 |

### Profiles & trade-offs (DevKitC-1)

The 480×480 RGB565 panel eats 20 GPIOs; with I2C/LED/I2S/backlight the 29 free pins
are full — **on-board SD and CAN can't both be added simultaneously**. Kconfig switches:

| Feature | Profile A (default) | Enable |
|---|---|---|
| LCD + touch + I2C sensors | ✅ | — |
| WS2812 (matrix/circle/bar) | ✅ | — |
| Audio (ES8311 full-duplex) | ✅ | — |
| Backlight PWM dimming | ✅ | — |
| On-board microSD | ❌ (D0=42 clashes I2S) | `CONFIG_AGENTIND_ENABLE_SD`, disable audio or re-route |
| CAN/TWAI | ❌ (43/44 clash backlight/I2S) | `CONFIG_AGENTIND_ENABLE_CAN`, re-route TWAI via GPIO matrix |

> A production bare-module board wanting full features needs a **serial RGB (SPI/QSPI)
> panel** or IO expanders / shift registers to free up data lines; DevKitC-1 prototyping
> validates display+audio+LEDs+sensors via Profile A.

## 2.2 LCD Backlight Constant-Current Driver & Dimming

**LED_A/LED_K are the anode/cathode of the panel's internal backlight LED string.**

**Confirmed backlight spec**: **If = 80mA, Vf typ 3.2V (Min 2.8 / Max 3.3V)**.
Vf < 5V0 → **no boost needed**; a low-voltage linear constant-current source suffices
(single string / all-parallel).

- **Default**: a 5V0-input linear CC source at 80mA:
  - CC IC: **NSI45080** (fixed 80mA) or **BCR401U / AMC7140** (settable), SOT-23/89, minimal externals;
  - dropout loss (5.0−3.2)×0.08 ≈ **0.144W**, small package + copper pour is enough;
  - `EN` ← TCA9554 `EXP_LCD_BL_EN` (slow on/off); `PWM/CTRL` ← MCU `GPIO43` (LEDC 2kHz PWM).
- **Cheaper**: drive via a series resistor — R ≈ (5.0−3.2)/0.08 ≈ **22Ω**, ~0.14W (0805/1206).
  Downside: current drifts with Vf/temperature. A 0Ω jumper selects "CC IC / resistor".
- **Dimming**: firmware `display_set_backlight(pct)` (LEDC 8-bit duty); the Lighting page
  brightness slider drives both LED global brightness and the LCD backlight.

## 2.3 DevKitC-1 Adapter Board

The prototype is an **ESP32-S3-DevKitC-1 (N16R8)** on an adapter carrying TCA9554,
AHCT125 level shifter, ES8311+NS4150B audio, backlight CC IC, the LCD 40P FPC socket,
WS2812 SH1.0 outlets, a Qwiic I2C header (IMU/SHT4x/BMP280/PCF8563) and the power DCDCs.
See §2 for the pinmap and Profile trade-offs.

**All 29 usable GPIOs are consumed**; slow controls go through TCA9554:

| TCA9554 | Signal |
|---|---|
| P0 | LCD_RST |
| P1 | TP_RST (CST836U) |
| P2 | LCD_BL_EN |
| P3 | PA_EN (NS4150B) |
| P4 | LED_PWR_EN (VLED PMOS) |
| P5 | LCD_SPI_CS (ST7701 3-wire init SPI; SCK/SDA borrow LCD lines, released after init) |
| P6 | CHG_INT (MP2760, input) |
| P7 | TP_INT (input; touch is polled at 20ms, INT is a wake assist) |

I2C address map: CST836U 0x15 · TCA9554 0x20 · QMI8658C 0x6B · INA226 0x40 · MP2760 0x5C (verify) · 24C02 (variant-D tiles) 0x50-0x53.

## 2.1 LCD 40P FPC Pinout (actual module spec)

Module: ST7701 + CST836U, outline 73.03 × 76.48 × **2.34mm**, AA 70.13×70.13, SPI/RGB dual mode.

| FPC pin | Signal | Connection |
|---|---|---|
| LED_A / LED_K ×2 | backlight anode/cathodes | via a constant-current backlight driver (see §2.2), not a bare resistor |
| GND ×3 | ground | — |
| VCI | panel supply | VDD 3.3V |
| RESET | panel reset | TCA9554 P0 (LCD_RST) |
| NC ×2 | — | — |
| SDA / SCK / CS | init SPI (9-bit 3-wire) | SDA←LCD_G0 net, SCK←LCD_PCLK net, CS←TCA9554 P5; the panel has dedicated SPI pins — only the MCU side borrows RGB GPIOs |
| PCLK / DE / VSYNC / HSYNC | RGB timing | GPIO14 / 47 / 45 / 46 |
| DB0–DB17 | 18-bit RGB data | RGB565 wiring: R4..0←DB17..13, G5..0←DB11..6, B4..0←DB5..1; **DB0 & DB12 to GND** (standard 666→565 drop, confirm against the panel datasheet) |
| TP_INT / TP_SDA / TP_SCL / TP_RESET / TP_VCI | CST836U touch | TCA9554 P7 / I2C_SDA / I2C_SCL / TCA9554 P1 / VDD |

## 3. ST7701 Init Path

The RGB panel needs its init sequence over 3-wire 9-bit SPI first. Borrowed lines
(same as Espressif EV boards): `SPI_SCK ← LCD_PCLK`, `SPI_SDA ← LCD_G0`,
`CS ← TCA9554 P5`. Bit-banged during init, then the pins are reconfigured to the
LCD_CAM RGB peripheral. See the two-stage init in `display.c`.

## 4. LED Carrier Boards

| Board | Contents | Interface |
|---|---|---|
| Matrix 8×8 | 64×WS2812B, 64×64mm, corner mounting holes; DIN/DOUT on 2.54-3P both sides for 4-tile S-cascade | VLED/GND/DATA |
| Circle | 24×WS2812B ring ID75/OD85, hollow center for the LCD FPC | same |
| Bar family | per-variant lengths, SH1.0-3P both ends (chainable) | same |

Each board: 33Ω series at DIN + 104 per LED + 220µF at the inlet.

## 5. Layout Zones (main board, est. 90×70mm, 4 layers)

```
┌─────────────────────────────────────────┐
│ [XT30][CAN] Sheet1/2 power   [USB-C PD] │  ← rear edge: all external I/O
│  inductors/MOS away ▼        [USB-C data]│
│ Sheet3 DCDC ──┐   ┌─ Sheet4 MCU (antenna │
│  VLED high-A  │   │   at edge, keepout)  │
│ ──────────────┴───┴───────────────────── │
│ Sheet7 AUDIO (away from DCDC) Sheet5/6/8 │
│  short mic traces            FPC/LED/SD  │
└─────────────────────────────────────────┘
```

- VLED 5A path: 2oz copper, ≥4mm traces, buck output straight to the LED connector.
- Wi-Fi antenna keepout ≥15×6mm, nothing underneath.
- Mic analog guarded with ground, away from PCLK (20MHz) and buck switch nodes.
- 16 RGB data lines length-matched (±5mm is fine at 20MHz), group-guarded.

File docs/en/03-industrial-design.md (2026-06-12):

# Agent Indicator — Industrial Design (4 variants)

> Rev 0.2 · 中文版: [../03-industrial-design.md](../03-industrial-design.md)
> 3D sources & printable STL: [`hardware/3d/`](../../hardware/3d/) (OpenSCAD)
>
> Shared design language: the **Halo unit** — the LCD (70.13mm square AA) sits right
> behind the LED Circle (ID75/OD85); the ring hides the screen corners (AA diagonal
> 99.2mm > 75mm aperture). With a circular UI it reads as one "glowing round display".
> Keep a 3–4mm step between ring and panel plus a matte-black inner wall so ring light
> doesn't bleed onto the screen.

Common finish: CNC anodized aluminum or resin-printed shell, bead-blasted; 2mm milky
acrylic diffuser (~40% transmission); ≥8mm LED-to-diffuser distance with grid baffles
(8×8mm cells on the matrix to stop cross-bleed); silicone feet + ballast.

---

## Variant A "Halo" — round single unit, most compact

Halo unit + base only. Usage is drawn as arc segments along the round UI edge; context
as a ring heat map (no matrix). The "smallest cute" build; a matrix can magnet-attach
later as a variant-D tile.

Halo 3D render

| Item | Value |
|---|---|
| Head | Ø100 × 32mm (OD85 ring + 7.5mm bezel) |
| Base | 110 × 70 × 30mm, rounded |
| Mic bar | 48LED @ 99mm, front face of the base |
| Battery | 3×18650 flat in the base |
| Volume / weight est. | ~0.31L / ~420g (with cells) |

---

## Variant B "Console" — landscape one-piece, recommended primary

Full-featured. Matrix left, vertical usage bar center, Halo right, full-width mic bar
along the bottom edge, 15° wedge stance.

Console 3D render
Console front

| Item | Value |
|---|---|
| Overall | 176 × 112 × 42mm (rear), 18mm front edge |
| Layout | Matrix left (center 40mm from left), usage bar center, Halo right (center 48mm from right) |
| Mic bar | 64LED @ 132mm, bottom center; 2 mics at the ends |
| Battery | 3×18650 across the tall rear section |
| Speaker | Ø28 downfiring chamber |
| Volume / weight est. | ~0.55L / ~580g |

16×16 upgrade path: the left zone reserves 134×134mm for a 4-tile panel
("Console XL" shell at 246mm wide, internals unchanged).

---

## Variant C "Totem" — vertical, smallest footprint

Stacked: Halo → matrix → base; usage bar on the right edge, mic bar on the base front.
Footprint only 78×62mm.

| Item | Value |
|---|---|
| Overall | 78 × 240 × 62mm (base 90mm deep for stability) |
| Mic bar | 20LED @ 41.5mm (base width limit) |
| Battery | 3×18650 upright in the base |
| Notes | Halo at eye level; IMU cuts VLED on tip-over |

---

## Variant D "Tiles" — magnetic modules, most playful

Unified **90×90×22mm** tile frame (fits the largest parts: ring OD85 / LCD 76.48).
Magnets + 4P pogo (VLED / GND / DATA-IN / DATA-OUT) on edge midpoints; dovetail into a
powered dock rail. Four matrix tiles in 2×2 give native 16×16.

Tiles 3D render

| Item | Value |
|---|---|
| Tile | 90 × 90 × 22mm, ~0.8kg magnetic retention (Ø8×3 N magnets ×4) |
| Dock | 370 × 60 × 26mm (4 slots), or 190mm 2-slot |
| Mic bar | 80LED @ 164.7mm in the dock front edge (48LED@99mm for the short rail) |
| Electrical | VLED bus in the rail + WS2812 data daisy-chained through pogo across tiles; per-tile EEPROM (24C02) type ID, enumerated at boot |
| 16×16 | 4 matrix tiles snap 2×2 off-rail, edge pogos S-route the data, the block then takes 1 rail slot |

---

## Variant E "Soundbar" — under-monitor bar

Slides into the gap under a monitor stand; the 12°-tilted front face puts everything
toward the user: 8×8 matrix left (compact 48mm pitch), a shrunken Halo center
(Ø47 ring + a 1.28" round LCD such as GC9A01), horizontal usage bar right, and a
full-width **160LED@329mm mic bar** along the bottom edge.

Soundbar 3D render

| Item | Value |
|---|---|
| Overall | 340 × 58 × 54mm, front tilted 12° |
| Mic bar | 160LED @ 329mm (longest in the line, best VU) |
| Display | central Halo uses a 1.28" round LCD, ring shrinks to Ø47 |
| Battery | 2×18650 (height-limited), or battery-less USB-PD |
| Notes | mics at both ends, away from monitor speakers |

## Variant F "Orb" — spherical desk pet

A Ø110 sphere with a flattened front carrying the Halo, ambient ring glowing at the
base, gazing up 12° at the user. Status + I/O only (no matrix/usage — they live in
the round UI). The most affective, lowest-part-count form; the base ring reuses the
Circle LED board.

Orb 3D render

| Item | Value |
|---|---|
| Overall | Ø110 sphere + Ø96 weighted base, ~135mm tall |
| LEDs | front Circle 24 + base ambient ring (two Circle boards) |
| Battery | 1×18650 centered as ballast, or 21700 |
| Notes | IMU tap = confirm gesture; two CNC/printed hemispheres bonded at the equator |

## Comparison & Recommendation

| | A Halo | B Console | C Totem | D Tiles | E Soundbar | F Orb |
|---|---|---|---|---|---|---|
| Feature completeness | ◐ (no matrix) | ● | ● | ●+ | ● | ◔ (status+IO only) |
| Compact / refined | ●● | ● | ● (smallest footprint) | ◐ (long rail) | ● (hides under monitor) | ●● (desk pet) |
| Mechanical difficulty | low | medium | medium | high (pogo/magnets/enum) | medium | medium (sphere seam) |
| 16×16 path | external | new shell | n/a | native | n/a | n/a |
| Positioning | entry / gift | **primary, build first** | derivative | flagship, phase 2 | always-on workstation | affective derivative |

**Suggested route**: build B (Console) first to validate all circuits and firmware →
reuse the Halo unit for A → phase 2 for D's dock and tiles. All four share one main
board (doc 04); only shells and LED carriers differ.

Dimensions assumed (correct with real parts in hand):
1. 18650 length 65mm (unprotected), holder envelope 58×78mm;
2. matrix board: PCB 1.6mm + LED 2.5mm;
3. ~~LCD module total thickness 3.5mm (with CTP)~~ confirmed: **2.34mm** (73.03×76.48×2.34 actual spec).

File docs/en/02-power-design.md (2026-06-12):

# Agent Indicator — Power Design

> Rev 0.2 · 中文版: [../02-power-design.md](../02-power-design.md) · Companion: [01-system-design.md](01-system-design.md)

## 1. Power Topology

```
USB-C PD ──► CH224K ──► VPD(15V≥3A) ──► ideal diode ─┐
  (request 15V)                        (LM5050-1+PFET)│
                                                      ├──► VIN_SEL ──► MP2760 ──► VSYS(9~12.6V)
XT30 ──► rev-prot PFET+TVS ──► VIN(12-24V) ─► ideal ──┘            (NVDC buck-boost   │
                                          diode (priority)         charger+power path)│
                                                                        ▲▼            │
                                            3S 18650 ◄── S-8254A prot ──┘             │
                                            (11.1-12.6V)  HY2213×3 balance            │
                                                                                      │
        ┌─────────────────────────────────────────────────────────────────────────────┤
        │                                     │                                       │
   TPS56637                               MP2315S                                     │
   VLED 5.0V/5A ──► PMOS sw (LED_PWR_EN)  5V0 2A ──┬─► TPS2121 ◄── VUSB (data-port VBUS)
   ──► WS2812B Matrix/Ring/Bars                    │   (seamless mux + anti-backfeed)
                                                   ├─► SGM2212-3.3 ──► VDD 3.3V
                                                   │    (SD card / IMU / codec logic / I2C)
                                                   └─► ferrite+tantalum ──► VAUDIO 5V (NS4150B)
```

Key points:
- **MP2760 NVDC power path**: when an input is present the system runs from it while charging; on input removal it switches to battery seamlessly — no extra switching circuit.
- **Input priority**: XT30 and VPD are ORed through ideal diodes. The XT30 branch gets a 30mV bias so it wins at equal voltage; at 24V XT30 wins naturally.
- **VLED / 5V0 isolation**: two independent bucks, LED ripple never reaches logic; the data-port VBUS only enters TPS2121, which muxes against 5V0 with no backfeed (USB debug works with main power removed; LEDs stay off).

## 2. Component Selection

| Node | Part | Key specs | Notes |
|---|---|---|---|
| PD sink | **CH224K** | requests 15V (CFG), 100W class | 15V > 12.6V + charge margin; LED pin indicates PD success |
| Input ORing | **LM5050-1** ×2 + PFET (AO4407A) | ideal-diode controller | LM74700 as integrated option |
| XT30 protection | reverse PFET + **SMBJ26A** TVS + NTC | 24V input | CAN 4P header (CANH/L/12V/GND) sits next to XT30 |
| Charger | **MP2760** | 1-4S NVDC buck-boost, I2C, VIN 2.7-22V, ≤6A | Charges 3S from either 12V XT30 or 15V PD; I2C status; alt. BQ25756 (controller + ext. FETs, more power) |
| Battery protection | **S-8254A** + dual NMOS | 3S OV/UV/OC/SC | classic solution; alt. BQ76905 (with gauge) |
| Balancing | **HY2213-BB3A** ×3 | 4.2V shunt 66mA per cell | simple, reliable end-of-charge balancing |
| Battery monitor | 3-cell dividers → MCU ADC + **INA226** (VSYS high side) | — | SoC estimate + power telemetry |
| VLED buck | **TPS56637** | 4.5-28V in, 6A | 5.0V output near the LED connectors; upstream PMOS gated by LED_PWR_EN |
| 5V0 buck | **MP2315S** | 4.5-24V, 3A | logic / audio |
| USB anti-backfeed | **TPS2121** | dual-input power mux, seamless | 5V0 (priority) vs VUSB → 5V0_SYS |
| VDD LDO | **SGM2212-3.3** | 1A, low dropout | SD peak ~200mA + headroom |
| VAUDIO | ferrite + 220µF | filtered from 5V0_SYS | decoupling for 3W class-D bursts |

## 3. Power Budget

WS2812B at a typical measured 16mA/channel (240mW/LED full white at 5V); firmware limits VLED to 4.5A.

| Load | Qty | Typical (animation @25%) | Peak (full white) |
|---|---|---|---|
| Matrix 8×8 | 64 | 0.77A | 3.07A |
| Matrix 16×16 (expansion) | 256 | 3.07A | 12.3A → firmware-limited |
| Circle | 24 | 0.29A | 1.15A |
| Usage 20 + mic bar 64 | 84 | 1.0A | 4.0A |
| **VLED total (8×8 build)** | 172 | **~2.1A / 10.4W** | limited 4.5A / 22.5W |
| LCD (panel+backlight) | — | 1.2W | 1.5W |
| ESP32-S3 (Wi-Fi active) | — | 0.8W | 1.7W |
| Audio (3W PA bursts) | — | 0.2W | 3W |
| **System total** | — | **~14W** | ~29W |

- PD 15V×3A = 45W: covers system peak + ~1A charge; at 24V on XT30 charging can go to 2A.
- Runtime: 3S×3000mAh ≈ 33Wh, typical 14W → **~2.3h**; standby (LEDs off, LCD dim) <1.5W → >20h.
- 16×16 expansion: recommend XT30 power; the limiter caps full-white at 4.5A (~35% average brightness); a second TPS56637 footprint is reserved.

## 4. Protection & Details

1. **OV/UV**: S-8254A at 4.25V/2.7V per cell; MP2760 terminates at 12.6V, C/10 cutoff.
2. **Balancing**: HY2213 shunts 66mA when any cell reaches 4.2V; pairs with MP2760 end-of-charge taper.
3. **Anti-backfeed**: USB VBUS only enters TPS2121; VPD/VIN are one-way through ideal diodes; the VLED PMOS blocks reverse leakage from LED boards.
4. **Surge/ESD**: TVS at XT30; USBLC6-2SC6 on both USB-C ports; PESD1CAN on CAN.
5. **Thermals**: TPS56637 with copper pour + via array; MP2760 ~1W loss at 2A charge, same treatment.
6. **Power-up sequencing**: VDD before LED_PWR_EN/BL_EN (firmware-delayed via TCA9554) to avoid WS2812 flash at power-on.
7. **Sensing**: per-cell dividers 100k/10k + RC into ADC (taps before the protection board), static drain <15µA.

## 5. Connectors

| Interface | Connector | Pins |
|---|---|---|
| PD input | USB-C 16P (PD only) | CC to CH224K |
| Data USB | USB-C 16P | D+/D- → GPIO19/20, VBUS → TPS2121 |
| External power | XT30-M | 12-24V |
| CAN | XH2.54-4P | 12V / CANH / CANL / GND (120Ω jumper at the end) |
| Battery | XH2.54-4P (B-,B1,B2,B+) | full balance leads |
| LED outputs | SH1.0-3P ×3 | VLED / DIN / GND (matrix tiles cascade via 2.54 headers) |
| Expansion I2C | SH1.0-4P (Qwiic-compatible) | 3V3 / GND / SDA / SCL |

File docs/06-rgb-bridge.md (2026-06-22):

# 06 · RGB Bridge — 用第二颗 ESP32-S3 省下主板 RGB 引脚

## 为什么需要
ST7701S 480×480 是 **RGB 并口屏**:RGB565 要 16 数据 + 4 同步(PCLK/DE/VSYNC/HSYNC)
+ 3 线 SPI 初始化 ≈ **23 根 GPIO**。主板(Agent Indicator)引脚紧张,直接驱动会吃光 GPIO。

**方案**:用一颗**专职的第二颗 ESP32-S3 当"桥片"**驱动 RGB 屏,主板只用 **4 根 SPI**
把画面帧推给桥片。主板因此**省下约 20 个 GPIO**。

```
  主板 ESP32-S3 ──(4 线 SPI 主)──▶ 桥片 ESP32-S3 ──(RGB565 并口 23 线)──▶ ST7701S 480×480
   RgbBridgeHost                      RgbBridge
```

## 两个工程
| 工程 | 角色 | 关键文件 |
|---|---|---|
| `RgbBridge/` | 桥片(SPI 从):收帧 + 驱动 ST7701S + 自测点屏 | `rgb_panel.c`(ST7701S/RGB)、`patterns.c`(自测)、`link_spi.c`(收帧) |
| `RgbBridgeHost/` | 主机(SPI 主):按协议推帧 | `rgb_bridge_host.c`(`push_line`/`push_frame`)、`app_main.c`(彩条测试) |

## 硬件约束(必读)
- **ESP32-S3 RGB 并口最多 16 数据线 = RGB565**,做不了 24 位 RGB888 并口。
  → 面板侧固定 **RGB565 输出**;主机推 **565 或 888 都收**,888 在桥片上转 565。
- 桥片需 **PSRAM**(RGB 双帧缓冲 + 暂存,占用约 1.84MB / 8MB)。
- ST7701S 厂商序列里 `COLMOD=0x66`(RGB666 18bit),16 根数据线接面板**高位**即可
  (RGB565→666 各色丢 1 LSB,肉眼无感)。

## 桥片引脚(`RgbBridge/main/board.h`,按转接板实际接线改)
| 用途 | GPIO |
|---|---|
| RGB565 数据 B0-4 / G0-5 / R0-4 | 4,5,6,7,8 / 9,10,11,12,13,14 / 15,16,17,18,21 |
| PCLK / DE / VSYNC / HSYNC | 39 / 40 / 41 / 42 |
| ST7701 初始化 3 线 SPI:CS / SCL / SDA | 45 / 47 / 48 |
| RST / 背光 BL | 46 / 44 |
| 主机 SPI 从机:CS / CLK / MOSI / MISO | 1 / 2 / 38 / 43 |

## 主机↔桥片接线(4 根 + 共地)
| 主机 RgbBridgeHost | → | 桥片 RgbBridge |
|---|---|---|
| PIN_CS 15 | → | HOST_SPI_CS 1 |
| PIN_CLK 16 | → | HOST_SPI_CLK 2 |
| PIN_MOSI 17 | → | HOST_SPI_MOSI 38 |
| PIN_MISO 18 | → | HOST_SPI_MISO 43(可不接) |

## 线协议(主机推帧)
SPI 模式 0;**每个 SPI 事务 = 一行包**:

| 字节 | 含义 |
|---|---|
| [0] | `0xA9` 魔数(帧同步,错位包丢弃) |
| [1] | 格式:`0`=RGB565 小端,`1`=RGB888 |
| [2..3] | 行号 y(小端 u16) |
| [4..] | 该行 480 像素(565:960B / 888:1440B) |

主机连续推 y=0..479;桥片收到 `y==479` 即整帧刷新上屏。收到首个合法包后桥片**自测停止**。
默认链路 20MHz(`LINK_CLK_HZ`)≈ 5fps@565,可上调。

## 面板初始化与时序(已按本屏手册配好)
- **初始化序列**:`board.h` 的 `USE_VENDOR_INIT`,`1`=面板厂商专属序列
  (`rgb_panel.c` 的 `s_vendor_init[]`,Gamma/VCOM=32/VGH=15V/AVDD=6.6V),`0`=组件通用默认。偏色/不亮两版都试。
- **RGB 时序**(来自面板手册 480RGB×480 Timing Table,取 Typ):
  PCLK **20MHz**,HSYNC 脉宽 **8**/后肩 **60**/前肩 **60**,VSYNC 脉宽 **4**/后肩 **20**/前肩 **20**。
  (手册 Thw 处 Typ20 与 Max8 矛盾,取 Max=8。)

## 编译 / 烧录 / 验证
```bash
. /home/zhe/Code/esp-idf/export.sh
# 桥片
cd RgbBridge && idf.py set-target esp32s3 && idf.py build flash monitor
# 主机(另一颗 S3)
cd ../RgbBridgeHost && idf.py set-target esp32s3 && idf.py build flash monitor
```
1. **单烧桥片** → 屏应循环显示纯色/彩条/渐变/棋盘/白边框(确认时序/初始化对);
2. **再烧主机 + 接 4 线** → 桥片自测让位,屏上出现**移动彩条**(全链路通);
3. 之后把 `rgb_bridge_push_frame()` 接到真实画面源(LVGL 帧缓冲)即可。

## 后续可优化(v1 已能用)
- 双缓冲 + DMA 链 + 握手 GPIO 提帧率;
- 脏矩形/分块刷新(只推变化区域);
- MISO 回状态/帧号做流控。

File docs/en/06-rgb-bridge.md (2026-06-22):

# 06 · RGB Bridge — offload ST7701S RGB pins to a second ESP32-S3

## Why
ST7701S 480×480 is an **RGB parallel** panel: RGB565 needs 16 data + 4 sync
(PCLK/DE/VSYNC/HSYNC) + 3-wire SPI init ≈ **23 GPIOs**. The main board can't spare that.

**Solution:** a dedicated **second ESP32-S3 "bridge"** drives the RGB panel; the main board
pushes frames over just **4 SPI wires**, saving ~20 GPIOs on the main board.

```
  Main ESP32-S3 ──(4-wire SPI master)──▶ Bridge ESP32-S3 ──(RGB565 parallel 23)──▶ ST7701S 480×480
   RgbBridgeHost                            RgbBridge
```

## Two projects
| Project | Role |
|---|---|
| `RgbBridge/` | Bridge (SPI slave): receive frames + drive ST7701S + standalone self-test |
| `RgbBridgeHost/` | Host (SPI master): push frames (`push_line`/`push_frame`) + moving-bars test |

## Hardware constraints
- ESP32-S3 RGB bus is **max 16 data lines = RGB565**; true 24-bit RGB888 parallel is not
  possible on S3. Panel output is fixed RGB565; host may send **565 or 888** (888 → 565 on bridge).
- Bridge needs **PSRAM** (~1.84 MB for RGB double buffer + staging).
- Vendor init uses `COLMOD=0x66` (RGB666 18-bit); wire the 16 lines to the panel's high bits.

## Wire protocol (one SPI transaction = one line)
`[0]=0xA9 magic  [1]=fmt(0=RGB565LE,1=RGB888)  [2..3]=y (LE u16)  [4..]=480 px`
Bridge refreshes the panel when it receives `y==479`. First valid packet stops the self-test.

## Init & timing (already set for this panel)
- `USE_VENDOR_INIT` in `board.h`: `1`=panel vendor sequence (`s_vendor_init[]`), `0`=component default.
- RGB timing from the panel datasheet (Typ): PCLK 20 MHz; HSYNC pw 8 / bp 60 / fp 60;
  VSYNC pw 4 / bp 20 / fp 20.

## Build / verify
```bash
. /home/zhe/Code/esp-idf/export.sh
cd RgbBridge      && idf.py set-target esp32s3 && idf.py build flash monitor
cd RgbBridgeHost  && idf.py set-target esp32s3 && idf.py build flash monitor
```
1. Flash bridge alone → cycling test patterns confirm the panel lights up.
2. Flash host + connect 4 wires → moving color bars confirm the full link.
3. Then feed `rgb_bridge_push_frame()` from your real source (LVGL framebuffer).

See `docs/06-rgb-bridge.md` (中文) for full pin tables and details.

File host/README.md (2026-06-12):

# agentind — 上位机转发软件

中文 | [English](README.en.md)

读取 LLM(Claude Code)状态,按 [协议](../docs/01-system-design.md#5-通讯协议host--device) 编码后经
Wi-Fi WebSocket / SocketCAN / USB vendor EP 推送到 Agent Indicator。

## 安装

```bash
cd host
pip install -e .            # 基础(ws)
pip install -e ".[all]"     # + can/usb 支持
```

## 运行

```bash
agentind run                          # claude-code 源 + mDNS 发现设备(Wi-Fi)
agentind run -s demo -v               # 演示动画,联调硬件用
agentind run -t can --channel can0    # SocketCAN(先 ip link set can0 up type can bitrate 500000)
agentind run -t usb                   # USB 自定义端点(303a:82a9)
```

## Claude Code 状态接入

默认 tail `~/.claude/projects/**/*.jsonl` 推断状态;如需更实时,在
`~/.claude/settings.json` 增加 hooks,事件会推到内置 listener(127.0.0.1:8765):

```json
{
  "hooks": {
    "UserPromptSubmit": [{"hooks": [{"type": "command",
      "command": "curl -s -m1 -X POST -d @- http://127.0.0.1:8765/event"}]}],
    "Stop": [{"hooks": [{"type": "command",
      "command": "curl -s -m1 -X POST -d @- http://127.0.0.1:8765/event"}]}],
    "PreToolUse": [{"hooks": [{"type": "command",
      "command": "curl -s -m1 -X POST -d @- http://127.0.0.1:8765/event"}]}],
    "Notification": [{"hooks": [{"type": "command",
      "command": "curl -s -m1 -X POST -d @- http://127.0.0.1:8765/event"}]}]
  }
}
```

## 结构

```
agentind/
  protocol.py        帧编码/解码、消息定义(与固件 main/proto 对应)
  transports/        ws(mDNS 发现) / can(分段重组) / usb(bulk EP)
  sources/           claude_code(JSONL tail + hooks listener) / demo
  cli.py             agentind run
```

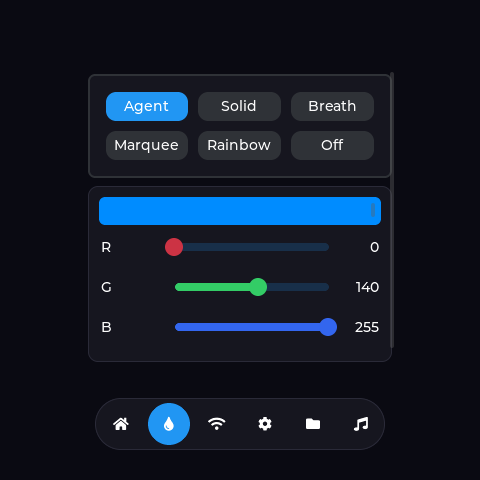
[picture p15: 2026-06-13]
tools/ui_sim/shots/ui-light.bmp

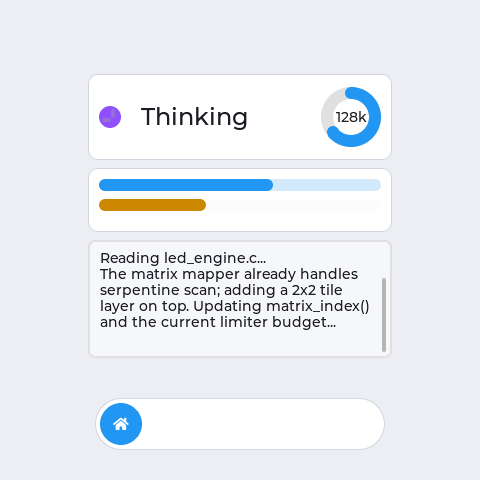
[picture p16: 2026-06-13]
tools/ui_sim/shots/ui-light-home.bmp

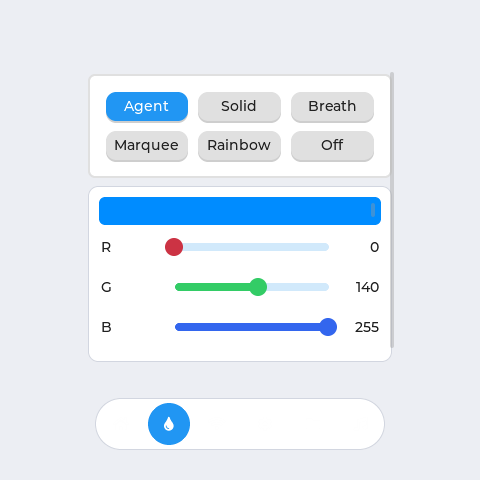
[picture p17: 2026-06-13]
tools/ui_sim/shots/ui-light-light.bmp

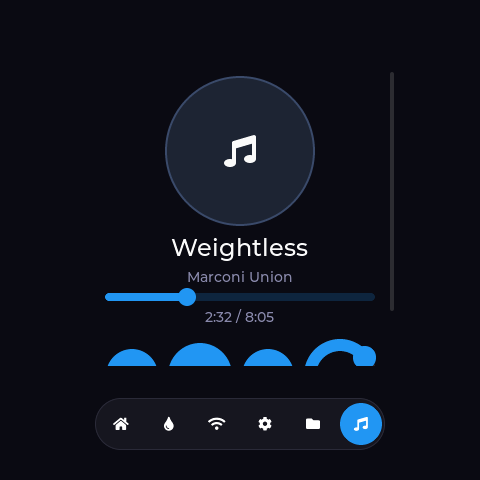
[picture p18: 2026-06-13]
tools/ui_sim/shots/ui-music.bmp

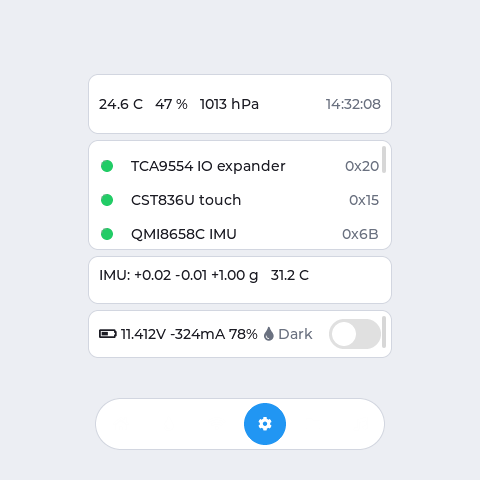
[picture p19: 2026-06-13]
tools/ui_sim/shots/ui-light-devices.bmp

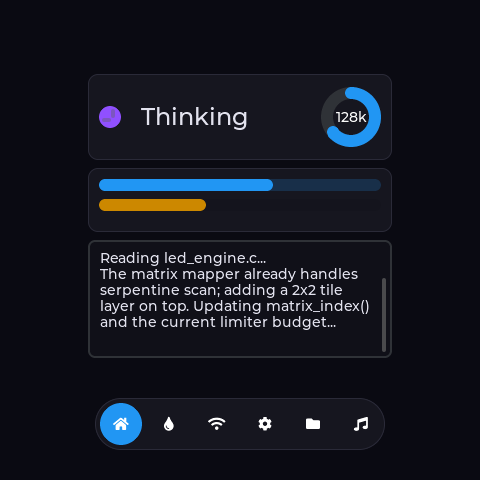
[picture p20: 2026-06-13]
tools/ui_sim/shots/ui-home.bmp

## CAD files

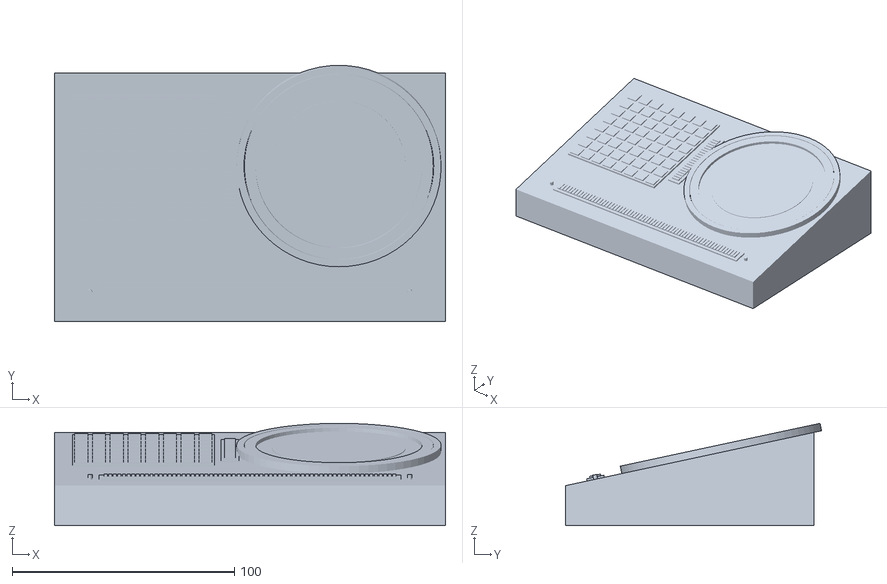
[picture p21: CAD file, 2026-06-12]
hardware/3d/console.stl
176.0 x 115.4 x 46.0

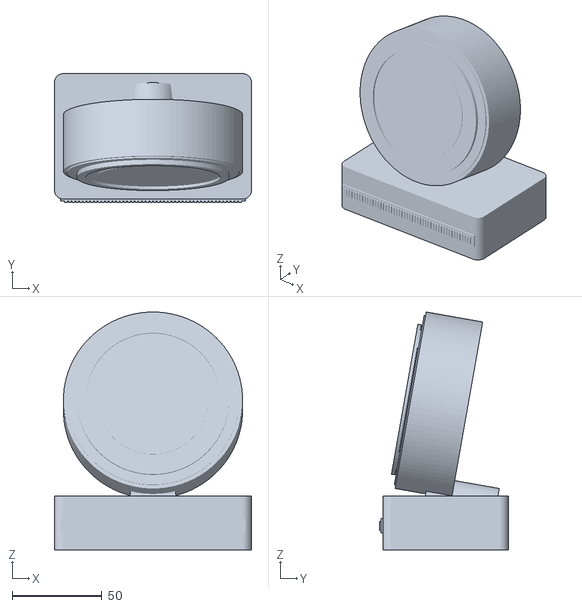
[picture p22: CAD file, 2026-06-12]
hardware/3d/halo.stl
110.0 x 71.8 x 132.8

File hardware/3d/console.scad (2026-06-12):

// Agent Indicator — 方案 B「Console」横向一体桌搭
// 176 × 112 × 42mm 楔形(前缘 18mm),与 docs/03 §方案 B 尺寸一致
// 渲染:xvfb-run openscad -o console.png --imgsize=1600,1200 console.scad

$fn = 64;

W = 176;        // 宽
D = 112;        // 深
H_BACK = 42;    // 后部高
H_FRONT = 18;   // 前缘高
SLOPE = atan((H_BACK - H_FRONT) / D);  // ≈12.1°
SLANT = sqrt(D * D + pow(H_BACK - H_FRONT, 2));

C_BODY   = [0.16, 0.17, 0.19];
C_PANEL  = [0.09, 0.09, 0.11];
C_OFF    = [0.13, 0.13, 0.15];
C_RING   = [0.55, 0.75, 1.0];
C_SCREEN = [0.05, 0.07, 0.12];

// 斜面坐标系:u=横向(0..W),v=沿斜面从前缘起(0..SLANT),children 立在面上
module on_face(u, v) {
    translate([u, v * cos(SLOPE), H_FRONT + v * sin(SLOPE)])
        rotate([SLOPE, 0, 0]) children();
}

// ---- 机体 ----
module body() {
    color(C_BODY) polyhedron(
        points = [
            [0, 0, 0], [W, 0, 0], [W, D, 0], [0, D, 0],
            [0, 0, H_FRONT], [W, 0, H_FRONT], [W, D, H_BACK], [0, D, H_BACK]
        ],
        faces = [
            [0, 1, 2, 3], [4, 7, 6, 5], [0, 4, 5, 1],
            [1, 5, 6, 2], [2, 6, 7, 3], [3, 7, 4, 0]
        ]);
}

// ---- 8×8 Matrix(context 热力图样式) ----
module matrix(cx, cv) {
    cell = 64 / 8;
    on_face(cx - 32, cv - 32) {
        color(C_PANEL) cube([64, 64, 1.2]);
        for (i = [0:7], j = [0:7]) {
            idx = j * 8 + i;
            lit = idx < 38;                       // ~60% context 已用
            cat = floor(idx / 13) % 5;
            c = !lit ? C_OFF
              : cat == 0 ? [0.35, 0.35, 0.42]     // system
              : cat == 1 ? [0.95, 0.55, 0.05]     // tools
              : cat == 2 ? [0.05, 0.6, 0.8]       // mcp
              : cat == 3 ? [0.6, 0.1, 0.8]        // memory
              : [0.05, 0.75, 0.4];                // messages
            color(c) translate([i * cell + 1, j * cell + 1, 1.2])
                cube([cell - 2, cell - 2, 0.8]);
        }
    }
}

// ---- Halo:LED Circle(OD85/ID75)套圆形显示 ----
module halo(cx, cv) {
    on_face(cx, cv) {
        color(C_SCREEN) cylinder(h = 1.5, d = 84);          // 屏面(被环遮角)
        color([0.1, 0.35, 0.7]) translate([0, 0, 1.5])
            cylinder(h = 0.4, d = 60);                       // 屏幕亮区示意
        color(C_RING) translate([0, 0, 1])
            difference() {
                cylinder(h = 2.2, d = 85);
                translate([0, 0, -1]) cylinder(h = 5, d = 75);
            }
        color(C_BODY) translate([0, 0, 0])
            difference() {                                   // 外饰圈
                cylinder(h = 3.4, d = 92);
                translate([0, 0, -1]) cylinder(h = 6, d = 85.5);
            }
    }
}

// ---- 竖直 Usage 条(20 段) ----
module usage_bar(cx, cv) {
    seg = 41.5 / 20;
    on_face(cx - 2.5, cv - 41.5 / 2) {
        color(C_PANEL) translate([-1.5, -1.5, 0]) cube([8, 44.5, 1]);
        for (k = [0:19]) {
            lit = k < 13;                                    // 65%
            c = !lit ? C_OFF : [k / 20, 1 - k / 20, 0.08];   // 绿→红
            color(c) translate([0, k * seg + 0.3, 1])
                cube([5, seg - 0.6, 0.8]);
        }
    }
}

// ---- 拾音条(64 LED @132mm,中心展开 VU) ----
module vu_bar(cx, cv) {
    n = 64; len = 132; seg = len / n;
    on_face(cx - len / 2, cv - 2.5) {
        color(C_PANEL) translate([-2, -1.5, 0]) cube([len + 4, 8, 1]);
        for (k = [0:n - 1]) {
            dist = abs(k - (n - 1) / 2) / (n / 2);
            lit = dist < 0.45;                               // 中心亮
            c = !lit ? C_OFF : [0.05, 0.5 + 0.4 * (1 - dist), 0.85];
            color(c) translate([k * seg + 0.25, 0, 1])
                cube([seg - 0.5, 5, 0.8]);
        }
    }
}

// ---- MIC 孔 ----
module mic_hole(cx, cv) {
    on_face(cx, cv) color([0.02, 0.02, 0.02]) cylinder(h = 2, d = 2);
}

body();
matrix(40, 72);          // 左:8×8 Matrix
usage_bar(79, 72);       // 中:Usage 竖条
halo(128, 72);           // 右:Halo(Circle+LCD)
vu_bar(88, 14);          // 前缘:拾音条
mic_hole(16, 14);
mic_hole(160, 14);

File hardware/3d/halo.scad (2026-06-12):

// Agent Indicator — 方案 A「Halo」圆形单体
// 本体 Ø100×32mm 后仰 10°,跑道形底座 110×70×30mm,前缘拾音条 48LED@99mm
// 与 docs/03 §方案 A 尺寸一致

$fn = 96;

C_BODY   = [0.16, 0.17, 0.19];
C_PANEL  = [0.09, 0.09, 0.11];
C_OFF    = [0.13, 0.13, 0.15];
C_RING   = [0.55, 0.75, 1.0];
C_SCREEN = [0.05, 0.07, 0.12];

TILT = 10;

// ---- 底座:圆角矩形 110×70×30(r=5,前缘直边 100mm 容纳拾音条) ----
module base() {
    color(C_BODY) hull()
        for (x = [-50, 50], y = [-30, 30])
            translate([x, y, 0]) cylinder(h = 30, r = 5);
}

// ---- 拾音条(48 LED @99mm)嵌底座前立面 ----
module vu_bar() {
    n = 48; len = 99; seg = len / n;
    translate([-len / 2, -35.01, 11]) rotate([90, 0, 0]) {
        color(C_PANEL) translate([-2, -1.5, 0]) cube([len + 4, 8, 1]);
        for (k = [0:n - 1]) {
            dist = abs(k - (n - 1) / 2) / (n / 2);
            lit = dist < 0.5;
            c = !lit ? C_OFF : [0.05, 0.5 + 0.4 * (1 - dist), 0.85];
            color(c) translate([k * seg + 0.25, 0, 1])
                cube([seg - 0.5, 5, 0.8]);
        }
    }
}

// ---- 本体:Ø100×32 圆柱,前面 Halo ----
module head() {
    translate([0, 12, 78]) rotate([90 - TILT, 0, 0]) {
        color(C_BODY) cylinder(h = 32, d = 100);          // 机身
        // 前面板(朝 -y 即朝观察者):放在 z=32 端
        translate([0, 0, 32]) {
            color(C_PANEL) cylinder(h = 0.8, d = 96);
            color(C_SCREEN) translate([0, 0, 0.8]) cylinder(h = 1.2, d = 84);
            color([0.1, 0.35, 0.7]) translate([0, 0, 2])
                cylinder(h = 0.4, d = 62);                 // 圆形 UI 亮区
            color(C_RING) translate([0, 0, 1.4])
                difference() {                              // LED Circle
                    cylinder(h = 2, d = 85);
                    translate([0, 0, -1]) cylinder(h = 5, d = 75);
                }
        }
    }
}

// ---- 颈部 ----
module neck() {
    color(C_BODY) translate([0, 8, 25]) rotate([90 - TILT, 0, 0])
        translate([0, 0, -20]) cylinder(h = 40, d = 26);
}

base();
vu_bar();
neck();
head();

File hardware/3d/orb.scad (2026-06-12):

// Agent Indicator — 方案 F「Orb」球形桌宠
// Ø110 球体,正面切平嵌 Halo(Circle OD85 + 圆形 UI),
// 底部环形配重座内嵌 24LED 氛围光环;最小可爱形态,仅 Status+IO。

$fn = 96;

C_BODY   = [0.16, 0.17, 0.19];
C_RING   = [0.55, 0.75, 1.0];
C_SCREEN = [0.05, 0.07, 0.12];
C_GLOW   = [0.2, 0.5, 0.9];

TILT = 12;

module orb() {
    translate([0, 0, 64]) rotate([TILT, 0, 0]) {
        // 球体,正面(-y)切平
        color(C_BODY) difference() {
            sphere(d = 110);
            translate([-60, -55 - 41, -60]) cube([120, 60, 120]);
        }
        // Halo 面板
        translate([0, -41.5, 0]) rotate([90, 0, 0]) {
            color(C_SCREEN) cylinder(h = 1.4, d = 86);
            color([0.1, 0.35, 0.7]) translate([0, 0, 1.4])
                cylinder(h = 0.5, d = 62);
            color(C_RING) translate([0, 0, 1])
                difference() {
                    cylinder(h = 2.4, d = 85);
                    translate([0, 0, -1]) cylinder(h = 6, d = 75);
                }
        }
    }
}

module base() {
    color(C_BODY) cylinder(h = 14, d1 = 96, d2 = 78);
    // 底缘氛围光环(透出桌面)
    color(C_GLOW) translate([0, 0, 1])
        difference() {
            cylinder(h = 2.5, d = 97);
            translate([0, 0, -1]) cylinder(h = 6, d = 88);
        }
}

base();
orb();

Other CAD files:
hardware/3d/soundbar.scad
hardware/3d/tiles.scad

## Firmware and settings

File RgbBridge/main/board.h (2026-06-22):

/* RgbBridge — 第二颗 ESP32-S3,把主机的 SPI 帧转成 ST7701S 480×480 RGB565 并口。
 * 引脚按 DevKitC-1(N16R8)分配,避开 flash(26-32)/PSRAM(33-37)/USB(19/20)/BOOT(0)。
 * strap 脚(45/46)仅作输出(init CS / RST),安全。按你的转接板实际接线改这里即可。 */
#pragma once

/* ---------- 面板侧:ST7701S RGB565(16 数据 + 4 同步 + 3线 SPI 初始化)---------- */
#define PANEL_H_RES   480
#define PANEL_V_RES   480

/* ST7701S 初始化序列选择:
 *   1 = 用面板厂商专属序列(LCD_INIT_CMD.txt,Gamma/VCOM/电压针对本屏);
 *   0 = 用 esp_lcd_st7701 组件内置通用默认序列。
 * 上板若偏色/不亮,两版都试一下。 */
#define USE_VENDOR_INIT  1

/* 16 根并口数据(RGB565,esp_lcd 约定顺序:[0..4]=B0..B4,[5..10]=G0..G5,[11..15]=R0..R4) */
#define RGB_B0  4
#define RGB_B1  5
#define RGB_B2  6
#define RGB_B3  7
#define RGB_B4  8
#define RGB_G0  9
#define RGB_G1  10
#define RGB_G2  11
#define RGB_G3  12
#define RGB_G4  13
#define RGB_G5  14
#define RGB_R0  15
#define RGB_R1  16
#define RGB_R2  17
#define RGB_R3  18
#define RGB_R4  21

#define RGB_PCLK   39
#define RGB_DE     40
#define RGB_VSYNC  41
#define RGB_HSYNC  42

/* ST7701S 上电初始化走 3 线 SPI(9-bit,CS/SCL/SDA);初始化完后这几根空闲 */
#define LCD_SPI_CS   45
#define LCD_SPI_SCL  47
#define LCD_SPI_SDA  48

#define LCD_RST      46    /* 复位;-1 = 软复位/外部 RC */
#define LCD_BL       44    /* 背光使能/PWM;-1 = 常亮接 VCC */

/* RGB 时序(来自面板手册 480RGB×480 Timing Table,取 Typ;Thw 取 8 因手册 Typ20/Max8 矛盾)*/
#define RGB_PCLK_HZ            (20 * 1000 * 1000) /* Fclk Typ 20MHz(范围 17~27) */
#define RGB_HSYNC_PULSE        8   /* Thw(Max 8;手册 Typ 20 与 Max 矛盾,取 8) */
#define RGB_HSYNC_BACK_PORCH   60  /* Thbp Typ */
#define RGB_HSYNC_FRONT_PORCH  60  /* Thfp Typ */
#define RGB_VSYNC_PULSE        4   /* Tvw Typ */
#define RGB_VSYNC_BACK_PORCH   20  /* Tvbp Typ */
#define RGB_VSYNC_FRONT_PORCH  20  /* Tvfp Typ */

/* ---------- 主机侧:SPI 从机(接收主机 ESP32 推来的帧)---------- */
#define HOST_SPI_CS    1
#define HOST_SPI_CLK   2
#define HOST_SPI_MOSI  38
#define HOST_SPI_MISO  43   /* 可选:回状态;不接也行 */

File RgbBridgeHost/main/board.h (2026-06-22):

/* 主机侧(主板 ESP32-S3)→ RgbBridge 的 4 线 SPI。
 * 这 4 个脚在主板上任选空闲 GPIO,接到桥片的 HOST_SPI_*(CS/CLK/MOSI/MISO)。
 * 示例用主板空闲脚 15/16/17/18(见 Demo 空闲引脚分析)。 */
#pragma once

#define PIN_CS    15
#define PIN_CLK   16
#define PIN_MOSI  17
#define PIN_MISO  18    /* 可选(回状态);桥片当前不回数据,接不接都行 */

#define LINK_CLK_HZ  (20 * 1000 * 1000)  /* 20MHz,稳;够 ~5fps@565。可上调试更高 */

#define PANEL_W  480
#define PANEL_H  480

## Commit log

2026-06-12 Agent Indicator: 设计文档 + Python 上位机 + ESP-IDF 固件
    - docs: 系统设计/电源/外观 4 方案/原理图划分
    - host: agentind Python 桥(ws/can/usb 三链路,Claude Code 状态源)
    - firmware: 协议栈 + 三链路 comm + 60fps LED 引擎 + LVGL9(ST7701/CST820,
    TinyTTF 字体,SPIFFS+SD 文件系统)+ ES8311 音频(rec/replay/SD 播放/录制/
    loopback)+ QMI8658C IMU 可视化 + USB Serial/JTAG 测试控制台(C++ cases)
    [partitions.csv]
2026-06-12 i18n + 英文文档 + 3D 模型渲染
    - firmware: ui/i18n 中英字符串表(NVS 持久化,console `lang`/协议 CONFIG key=3
    切换),display 状态标签跟随语言;澄清 TinyTTF(stb_truetype)非 FreeType
    - docs: 全套英文版 docs/en/ + README.en.md ×3,中英互链
    - hardware/3d: OpenSCAD 模型(Console/Halo)+ STL + 渲染图嵌入文档
    [console.scad, console.stl, halo.scad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]
2026-06-12 灯效引擎 + 六页 LVGL UI + PC 模拟器;log/REPL 改走 UART 串口
    - led_engine: OpenRGB 风格灯效(Solid 颜色可设/Breath/Marquee/Rainbow/Off),
    覆盖全部灯带,限流仍生效;console `light`/协议 CONFIG key=4/5 可控
    - UI 六页(固件与模拟器共用源码):Home 状态+IO 流 / Lighting 灯效控制 /
    Wi-Fi 扫描连接(密码键盘)/ Devices 设备检测+IMU/电源实时 / Files 浏览 / Music 播放
    - tools/ui_sim: LVGL PC 无头渲染,六页截图(docs/images/ui/)+ docs/05 UI 文档(中英)
    - 控制台/log 切到 UART0(43/44),USB 释放给 CDC/vendor;与 TWAI 引脚互斥已注记
    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
2026-06-12 新外观创意 ×3(Tiles/Soundbar/Orb)+ LCD 40Pin 实物规格入档
    - hardware/3d 新增:tiles(磁吸模块系统全景,含悬浮模块)、
    soundbar(显示器下横条,160LED 全宽拾音)、orb(球形桌宠)
    - docs/03(中英):方案 E/F 章节 + 渲染图 + 六方案对比表
    - docs/04(中英):LCD 40P FPC 引脚定义、RGB565 on 18-bit 接线
    (DB0/DB12 接地)、厚度修正为实物 2.34mm
    [orb.scad, soundbar.scad, tiles.scad]
2026-06-12 README 扩版(中英):特性表 + 外观/UI 图库 + 快速开始 + 文档导航 + 路线图
2026-06-13 UI 主题 Light/Dark + 环境传感器(SHT4x/BMP280/PCF8563 RTC)
    - screens: 双调色板 token + lv_theme dark/light 切换,Devices 页开关切换,
    NVS 持久化,on_rebuild 回调重填数据;全局字体指针支持 TTF
    - drivers/sensors: SHT4x 温湿度 / BMP280 气压(Bosch 补偿)/ PCF8563 RTC,
    共享 I2C,缺失安全降级
    - Devices 页展开:环境读数卡(温/湿/压+时钟)+ 11 项检测表(滚动)+ IMU/电源 + 主题开关
    - ui_sim 出 dark+light 各 6 张共 12 图;docs/05(中英)传感器表格 + 主题对比图
2026-06-13 DevKitC-1(N16R8)适配 + LCD 背光恒流 PWM 调光
    - 修正真 bug:GPIO33-37 被 octal PSRAM 占用,I2S DOUT/DIN 从 33/34 → 42/44
    - 背光:GPIO43 LEDC PWM(2kHz)→ 恒流驱动 IC DIM 脚,display_set_backlight(pct);
    EN 仍走 TCA9554;Lighting 亮度滑条联动 LED 与 LCD 背光
    - 日志/下载/REPL 改回 USB-Serial-JTAG(19/20),释放 43/44 给背光/I2S
    - Profile A 默认(显示+音频+背光+灯+传感器);SD/CAN 因引脚不足由 Kconfig 开关默认禁用
    - docs/04(中英):pinmap v0.2 + Profile 取舍表 + §2.2 背光恒流方案 + §2.3 DevKitC-1 转接板
    - board.h v0.2、Kconfig SD/CAN 开关、app_main/storage 条件化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
    [board.h, display.c, storage.cpp]
2026-06-13 README 表格修复 + 传感器/主题特性
    - 外观/UI 图库改用带标题表头的并排表格(空表头 | | | | 在 GitHub 渲染异常)
    - 特性表新增环境传感与界面主题两行;补 Light/Dark 主题对比图(中英)
2026-06-13 圆形屏 UI 重构 + 触摸/背光/PCLK 规格更新
    - 圆形屏适配:LCD 是 480×480 圆形 AA,弃用 lv_tabview(全宽底栏+贴边卡片四角被裁),
    改为居中安全区(320×300 落 R240 圆内)+ 底部居中 pill 导航(290 宽);截图叠圆形遮罩
    - 触摸芯片 CST820 → CST836U(全局,CST816 协议族,cst816s 驱动兼容,0x15)
    - 背光规格确认 If=80mA / Vf 3.2V(2.8-3.3):Vf<5V 无需 boost,改低压线性恒流
    (NSI45080/BCR401U,~0.144W)或 22Ω 限流;GPIO43 PWM 调光
    - LCD PCLK 16→20MHz(display.c 覆盖 timings;注明后期可上调)
    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
2026-06-13 音频 codec 同时支持 WM8960(与 ES8311 运行时探测二选一)
    - drivers/wm8960:I2C 0x1A,9-bit 寄存器,标准初始化(16bit I2S 从机,
    DAC→HP/SPK,LINPUT1→ADC),set_volume 调 HP+DAC;⚠ 寄存器值回板核对
    - audio.cpp:运行时探测 WM8960(0x1A)优先,否则 ES8311(0x18);音量/codec 名分发;
    I2S 增加 MCLK 引脚(BOARD_I2S_MCLK)——WM8960 需要 MCLK,不能像 ES8311 用 SCLK
    - board.h:I2C_ADDR_ES8311/WM8960、BOARD_I2S_MCLK(-1 默认,接 WM8960 时分配)
    - Devices 页 codec 行改 "Audio codec",detail 显实际型号(ES8311/WM8960)
    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
2026-06-17 新增 Demo 测试工程(DevKitC-1 + GC9A01 + WM8960)
    基于 firmware 裁剪的真机测试工程,适配 ESP32-S3-DevKitC-1(N16R8):
    - LCD 换 GC9A01(SPI 240×240 圆屏);音频默认 WM8960
    - WM8960 关键修复:板载 24MHz 晶振 → 内部 PLL 锁 12.288MHz SYSCLK
    (此前误按 MCLK 直连,DAC 实跑 93.75kHz 导致全程破音),48kHz 出声
    - I2C 全面迁移到 driver/i2c_master.h;新增 i2cdetect/i2cget/i2cset
    - 两路 WS2812 可分别控制:light [all|matrix|aux] <mode> ...
    - 新增 notify:一键爆闪 LED + 提示音,notify led/tone 可分别开关
    - 音频调试命令:wmreg/swap/scale;tone 扩到 0-9 + wave 波形发生器
    - audio_vol 无参读当前音量(影子值),默认 25%
    -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
    [partitions.csv]
2026-06-17 Demo: WM8960 当 I2S 主,根治间歇无声
    原理图(板载 24MHz 晶振常开供 MCLK)分析后定位:间歇无声源于双时钟域不相干
    ——ESP32 当主用自家时钟出 48k,WM8960 从机 DAC 却用 24M 晶振 PLL 的 SYSCLK,
    两个 48k 不锁定,上电/复位相位随机决定有无声。
    - WM8960 改为 I2S 主:R7=0x42(MS=1),R8=0x1C7(BCLKDIV÷8 → BCLK1.536M/LRCLK48k)
    - ESP32 改 I2S_ROLE_SLAVE;BOARD_I2S_MCLK=-1(不再输出 MCLK,免与晶振争用)
    → 全部音频时钟锁在单一 24MHz 源,反复复位/拔插电均稳定
    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
2026-06-22 新增 RGB Bridge 双工程 + 文档:第二颗 ESP32-S3 把 SPI 转 ST7701S RGB
    用专职桥片驱动 ST7701S 480×480 RGB 屏,主板只出 4 线 SPI,省下约 20 GPIO。
    - RgbBridge/(桥片,SPI 从):esp_lcd_st7701 + panel_io_additions 驱动 RGB565;
    自测图案(纯色/彩条/渐变/棋盘/边框,不接主机也点屏);SPI 从机逐行收帧
    (协议 [0xA9][fmt][y][行像素],565/888 均收,888→565);双帧缓冲走 PSRAM。
    面板厂商专属初始化序列 + 手册 RGB 时序(USE_VENDOR_INIT 可切组件默认版)。
    - RgbBridgeHost/(主机,SPI 主):push_line/push_frame 推帧驱动 + 移动彩条联调。
    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
